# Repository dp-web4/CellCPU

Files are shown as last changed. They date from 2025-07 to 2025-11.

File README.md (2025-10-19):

# CellCPU Documentation

**ModBatt Battery Management System - Individual Cell Controller**

## Overview

The CellCPU is a **production-ready** foundational component of ModBatt's hierarchical battery management system, providing individual cell monitoring and control for lithium-ion battery applications. Each CellCPU manages a single cell with precision voltage monitoring, temperature sensing, and active balancing control.

**Implementation Status**: ✅ **Complete and functional** - All core modules implemented with sophisticated interrupt-driven architecture.

### Quick Facts

- **Target Platform**: ATtiny45 microcontroller (8-bit AVR)
- **Cell Interface**: Direct monitoring of single lithium-ion cell
- **Temperature Sensor**: MCP9843 precision digital sensor
- **Communication**: Virtual UART at 20kbps in daisy-chain topology
- **Power Consumption**: <1mA typical operation
- **Scalability**: Up to 128 CellCPUs per ModuleCPU

## Web4 Ecosystem Context

CellCPU is the foundational layer of a **trust-native battery management system** demonstrating [Web4](https://github.com/dp-web4/web4) principles in production embedded hardware:

**Philosophy**: [Synchronism](https://github.com/dp-web4/Synchronism) - Distributed intelligence and scale-based autonomy
**Standard**: [Web4](https://github.com/dp-web4/web4) - Trust-native internet architecture with LCTs and MRH
**Implementation**: **CellCPU** (this) → [ModuleCPU](https://github.com/dp-web4/ModuleCPU) → [Pack-Controller](https://github.com/dp-web4/Pack-Controller-EEPROM)

### Web4 Integration

Each CellCPU operates as an autonomous agent with:
- **LCT Identity**: Unforgeable blockchain binding via hardware serial number
- **Markov Blanket**: VUART interface hides internal complexity from ModuleCPU
- **Local Intelligence**: Autonomous decision-making (balancing, error detection)
- **Trust Tensors**: ModuleCPU tracks T3 (Talent/Training/Temperament) and V3 (Veracity/Validity/Value)
- **Witnessed Presence**: ModuleCPU witnesses cell existence via VUART communication

See [WEB4_INTEGRATION.md](WEB4_INTEGRATION.md) for complete Web4 architecture details.

### Synchronism Principles

CellCPU demonstrates cosmic-to-silicon philosophy:
- **Scale-Based Autonomy**: Cell makes local decisions within module context
- **Markov Blankets**: VUART interface defines cell's reality boundary
- **Distributed Intelligence**: No central cell controller - intelligence emerges from hierarchy
- **Sensor Fusion**: Temperature + voltage + time → emergent "cell health"
- **Intent Dynamics**: Battery charge/discharge as metabolic intent propagation

See [SYNCHRONISM_PRINCIPLES.md](SYNCHRONISM_PRINCIPLES.md) for philosophical depth.

### Ecosystem Links

- [Synchronism Whitepaper](https://github.com/dp-web4/Synchronism/blob/main/whitepaper.md) - Universal principles
- [Web4 Standard](https://github.com/dp-web4/web4/blob/main/web4-standard/README.md) - Internet standard
- [ModBatt Web4 Examples](https://github.com/dp-web4/web4/blob/main/docs/modbatt_implementation_examples.md) - Code walkthroughs

**This is not just a battery controller - it's proof that Web4 trust architecture works in 4KB of flash memory.**

---

## Documentation Structure

### 📖 Core Documentation

#### [System Overview](docs/overview/README.md)
Complete system overview, architecture, and integration context within the ModBatt ecosystem.

- System role and responsibilities
- Hardware platform specifications  
- Communication protocol overview
- Performance characteristics
- Integration with ModuleCPU and Pack Controller

#### [Software Architecture](docs/overview/architecture.md)
Detailed firmware architecture and design patterns.

- Event-driven state machine design
- Module organization and dependencies
- Memory management strategies
- Interrupt architecture
- Error handling and safety systems

### 🔧 Hardware Documentation

#### [Hardware Platform](docs/hardware/README.md)
Comprehensive hardware platform documentation covering the ATtiny45 microcontroller and supporting components.

- ATtiny45 specifications and capabilities
- Pin configuration and multiplexing
- External component integration
- Power system design
- PCB layout considerations
- Environmental specifications

### 💻 Firmware Documentation

#### [Firmware Architecture](docs/firmware/README.md)
Complete firmware module documentation and implementation details.

- Module hierarchy and interfaces
- ADC voltage measurement system
- Virtual UART communication implementation
- Temperature sensor integration
- Platform abstraction layer
- Build system and optimization

#### [Cell Interface & Monitoring](docs/cell-interface/README.md)
Detailed cell monitoring and control system documentation.

- Voltage monitoring with 10-bit ADC
- Temperature sensing via I2C
- Active balancing control
- Safety and protection features
- Calibration and accuracy optimization
- Diagnostic capabilities

### 🔗 Communication System

#### [Communication with ModuleCPU](docs/communication/README.md)
Complete communication protocol and implementation documentation.

- Physical layer implementation
- Message format and structure
- Daisy-chain topology management
- Virtual UART timing and control
- Error handling and recovery
- Performance optimization

#### [Temperature Sensing](docs/temperature/README.md)
Comprehensive temperature monitoring system documentation.

- MCP9843 sensor integration
- I2C communication interface
- Thermal management and control
- Pin multiplexing with ADC
- Calibration and accuracy
- Error handling and diagnostics

### 🛠️ Development

#### [Development Environment](docs/development/README.md)
Complete development environment setup and workflow documentation.

- Required software tools (Microchip Studio, XC8)
- Hardware setup and programming
- Build process and optimization
- Testing and validation procedures
- Version control workflow
- Best practices and standards

#### [Implementation Status](docs/implementation-status.md)
**NEW**: Comprehensive review of actual implementation completeness and quality.

- Complete module implementation status
- Code quality assessment
- Production readiness evaluation
- Hardware validation priorities
- Integration testing recommendations

## Quick Start Guide

### 1. Development Environment Setup

```bash
# Required Tools
1. Download and install Microchip Studio 7.0+
2. Install XC8 Compiler v2.36+
3. Setup Atmel-ICE programmer/debugger
4. Clone the CellCPU repository

# Open Project
1. Launch Microchip Studio
2. File → Open → Project/Solution
3. Select CellCPU.cproj
4. Build → Build Solution (F7)
```

### 2. Hardware Configuration

```c
// Key hardware connections
Pin Configuration:
├── PB0: cell_up_tx    (Output to upstream cell)
├── PB1: cell_dn_rx    (Input from downstream)
├── PB2: I2C SDA       (Temperature sensor)
├── PB3: I2C SCL/ADC3  (Temperature + voltage)
├── PB4: cell_up_rx    (Input from upstream)
└── PB5: cell_dn_tx    (Output to downstream)

Power: 3.0V to 5.5V (5.0V nominal)
Programming: 6-pin ISP header
```

### 3. Basic Usage

```c
// Actual implemented functionality
System Operation:
1. Interrupt-driven Virtual UART communication (20kbps)
2. Pin-multiplexed voltage (ADC) and temperature (I2C) sensing
3. MCP9843 EVENT pin control for discharge balancing
4. Sophisticated timer-based bit timing with guard bits
5. Automatic chain position detection and data relay
6. Robust I2C bit-banged implementation with ACK handling
7. Power-efficient ADC enable/disable cycling

// Core modules all implemented:
├── adc.c - Complete ADC implementation with power management
├── I2c.c - Full bit-banged I2C with timing quantization  
├── mcp9843.c - Complete temperature sensor driver
├── vUART.c - Sophisticated interrupt-driven communication
└── main.c - Complete state machine coordination
```

## Key Features

### 🔋 Cell Monitoring
- **Voltage**: 10-bit ADC with 1.1V reference, ~4.3mV resolution
- **Temperature**: MCP9843 sensor, ±0.5°C accuracy, 0.0625°C resolution
- **Range**: 2.0V-5.0V cell voltage, -40°C to +125°C temperature

### 📡 Communication
- **Protocol**: Custom serial over Virtual UART
- **Speed**: 20kbps (50μs bit time)
- **Topology**: Daisy-chain up to 128 cells
- **Latency**: <5ms per cell response time

### ⚡ Control & Safety
- **Balancing**: Active discharge via MCP9843 EVENT pin
- **Protection**: Voltage and temperature limit monitoring
- **Safety**: Fail-safe operation on communication loss
- **Power**: <1mA typical, <100μA idle

### 🎯 Performance
- **Memory**: 4KB Flash (62% used), 256B SRAM (58% used)
- **Real-time**: Interrupt-driven with timer-based precision timing
- **Communication**: Sophisticated Virtual UART with guard bits and relay
- **I2C Implementation**: Professional bit-banged with timing quantization
- **Power Management**: ADC power cycling, efficient pin multiplexing
- **Reliability**: Comprehensive error handling and recovery mechanisms

## System Integration

### ModBatt Architecture Context

```
Vehicle Control Unit (VCU)
    ↓ CAN Bus
Pack Controller (STM32WB55)
    ↓ CAN Bus
ModuleCPU (ATmega64M1) ←→ Up to 128 × CellCPU (ATtiny45)
    ↓                              ↓
Battery Module                Li-ion Cells
```

### Communication Flow

```
Command Flow (Downstream):
ModuleCPU → CellCPU(Last) → CellCPU(Middle) → CellCPU(First)

Data Flow (Upstream):  
ModuleCPU ← CellCPU(Last) ← CellCPU(Middle) ← CellCPU(First)
```

## Contributing

### Development Workflow

1. **Feature Development**: Create feature branch from `develop`
2. **Code Review**: Submit pull request with comprehensive testing
3. **Integration**: Merge to `develop` after approval
4. **Release**: Create release branch for final testing
5. **Production**: Merge to `main` and tag release

### Coding Standards

- **Style**: K&R brace style, 4-space indentation
- **Documentation**: Comprehensive function headers and inline comments
- **Testing**: Unit tests and integration validation required
- **Performance**: Memory and timing optimization mandatory

## License and Patents

### Software License

This software is licensed under the **GNU Affero General Public License v3.0 or later** (AGPL-3.0-or-later).

See [LICENSE](LICENSE) for full license text.
See [LICENSE_SUMMARY.md](LICENSE_SUMMARY.md) for a summary of software vs. hardware licensing.

### Patents

Protected by US Patents:
- **11,380,942**: Distributed battery management with autonomous cell controllers
- **11,469,470**: Hierarchical battery management architecture
- **11,575,270**: Related pack control systems

**Patent Grant**: A limited patent grant for the software is provided under the AGPL-3.0 license scope. See [PATENTS.md](PATENTS.md) for details.

**Hardware Licensing**: Separate from software. See `docs/legal/ModBatt_Product_License.pdf` for hardware manufacturing licensing.

### Copyright

© 2023-2025 Modular Battery Technologies, Inc.

**Open Source Release**: October 2025 - Part of the Web4 trust-native ecosystem demonstration.

## Support and Contact

For technical support, development questions, or collaboration opportunities:

- **Technical Documentation**: See individual module documentation
- **Development Issues**: Check troubleshooting sections in relevant docs
- **Hardware Support**: Refer to hardware platform documentation
- **Communication Protocol**: See communication system documentation

---

## Related Projects

This repository can be viewed as demonstrating patterns of distributed trust and verifiable provenance in embedded systems.

**Related**: [Web4](https://github.com/dp-web4/web4) (trust architecture) • [Synchronism](https://github.com/dp-web4/Synchronism) (conceptual framing)

---

**Note**: This documentation covers the CellCPU firmware component of the ModBatt battery management system. For complete system documentation, refer to the Pack Controller and ModuleCPU documentation.

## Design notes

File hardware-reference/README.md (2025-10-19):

# CellCPU Hardware Reference Designs

**Status**: Reference designs for educational and non-commercial use
**Patent Coverage**: Protected by US Patent 11,380,942 (Distributed battery management with autonomous cell controllers)
**Last Updated**: October 2025

---

## Overview

This directory contains reference hardware designs for implementing the CellCPU concept - an autonomous cell-level battery management controller based on ATtiny45. These designs demonstrate one possible hardware implementation of the patented distributed battery management architecture.

**Contents**:
- KiCad schematics and PCB layouts
- Bill of Materials (BOM)
- Manufacturing files

---

## Patent Coverage

These hardware designs implement concepts covered by multiple patents in the ModBatt patent portfolio:

### Complete Patent List

**Modular Battery Technologies, Inc. Patent Portfolio**:

1. **US 11,380,942** (PCT/US21/50518) - *High Voltage Battery Module with Series Connected Cells and Internal Relays*
   - Filed: November 2, 2020 | Issued: July 5, 2022
   - Module with series connected cells and relays

2. **US 11,469,470** (PCT/US21/53798) - *Battery Module with Series Connected Cells, Internal Relays and Internal Battery Management System*
   - Filed: January 4, 2021 | Issued: October 11, 2022
   - Cell monitoring/conditioning circuit, PCBAs, methods

3. **US 11,563,241** - *Apparatus and Methods for Removable Battery Module with Internal Relay and Internal Controller*
   - Filed: February 10, 2021 | Issued: December 14, 2022
   - Authentication methods and circuits

4. **US 11,575,270** (PCT/US21/55047) - *Battery Module with Series Connected Cells, Internal Relays and Internal Battery Management System*
   - Filed: February 22, 2021 (CIP) | Issued: February 7, 2023
   - AC coupled comms and methods

5. **US 11,699,817** (PCT/US21/54434) - *Apparatus and Methods for Removable Battery Module with Internal Relay and Internal Controller*
   - Filed: March 31, 2021 | Issued: July 11, 2023
   - System, pack and module controllers, blockchain

6. **US 11,477,027** (PCT/US21/55813) - *Apparatus and Methods for Management of Controlled Objects*
   - Filed: May 11, 2021 | Issued: October 18, 2022
   - Multi-domain management of controlled objects, LCT/blockchain

7. **US 11,936,008** (PCT/US21/60860) - *Electrical Power System with Removable Battery Modules*
   - Filed: November 17, 2021 | Issued: March 19, 2024
   - Dissimilar modules in parallel

8. **US 12,278,913** (PCT/US22/24797) - *Apparatus and Methods for Management of Controlled Objects*
   - Filed: March 31, 2022 | Issued: April 15, 2025
   - Linking of identifiable records

9. **US 11,876,250** (PCT/US22/xxx) - *High Voltage Battery Module with Series Connected Cells and Internal Relays*
   - Filed: May 31, 2022 | Issued: January 16, 2024
   - Dissimilar relays, PLC control bus, linear and PWM modes

10. **US 12,046,722** - *Electrical Power System with Removable Battery Modules*
    - Filed: December 12, 2022 | Issued: July 23, 2024
    - Vehicle and stationary installations having a power system, energizing a bus

11. **US 12,405,309** - *Low Cost Battery Cell Monitoring Circuit*
    - Filed: January 3, 2023 | Issued: September 2, 2025
    - Low cost ASIC

12. **US 12,136,739** - *Low Cost Battery Cell Monitoring Circuit*
    - Filed: December 14, 2023 | Issued: November 5, 2024
    - Low cost ASIC methods

13. **US 12,142,737** - *Electrical Power System with Removable Battery Modules*
    - Filed: December 14, 2023 | Issued: November 12, 2024

14. **US 18/935,265** - *High Voltage Battery Module with 1-Phase and 3-Phase AC Output*
    - Filed: November 1, 2024 | Status: Pending

**Assignee**: Modular Battery Technologies, Inc.
**Inventors**: Dennis Palatov, et al.

### Key Patented Concepts in CellCPU Hardware

- Cell-level autonomous controllers with local intelligence
- Virtual UART communication in daisy-chain topology
- Distributed temperature and voltage monitoring
- Markov blanket interface hiding internal cell complexity
- Low-cost cell monitoring circuits and ASICs
- Authentication methods for cell controllers

---

## License and Usage Terms

### Software License
The **CellCPU firmware** (parent directory) is licensed under **AGPL-3.0-or-later** with a patent grant for software use. See `../LICENSE` for details.

### Hardware Reference Designs
These hardware reference designs are provided under the following terms:

#### ✅ Permitted Uses (Non-Commercial Patent Grant)

You MAY use these designs **without a commercial hardware license** for:

1. **Educational Use**: Academic research, teaching, and learning
2. **Personal/Hobby Use**: Individual projects and experimentation
3. **Research & Development**: Prototyping and testing new concepts
4. **Open Source Development**: Contributing to AGPL-licensed software improvements

**Conditions**:
- No commercial sale or distribution of manufactured hardware
- Acknowledge patent and provide attribution
- Derivative works must include similar non-commercial use notice
- Software modifications must comply with AGPL-3.0-or-later

#### ❌ Restricted Uses (Requires Commercial License)

You MUST obtain a commercial hardware license from Modular Battery Technologies, Inc. for:

1. **Commercial Manufacturing**: Producing hardware for sale
2. **Commercial Products**: Incorporating designs into commercial battery products
3. **Revenue Generation**: Any use where hardware generates revenue directly or indirectly
4. **OEM Integration**: Selling products that include these designs

**Contact**: For commercial licensing inquiries, contact Modular Battery Technologies, Inc.

---

## Technical Scope

These reference designs demonstrate:

- **Cell Controller**: ATtiny45-based autonomous controller per cell
- **Temperature Sensing**: MCP9843 I²C temperature sensor integration
- **Virtual UART**: Software-based serial communication at 20kbps
- **Daisy-Chain Topology**: Up to 128 cells in series connection
- **Voltage Monitoring**: Per-cell voltage measurement architecture
- **Relay Control**: Cell bypass/isolation relay interface

**Voltage Range**: Designed for 13-cell strings (48V nominal LiFePO4)

---

## AS-IS Disclaimer and Limitations

### ⚠️ NO WARRANTY

**THESE HARDWARE REFERENCE DESIGNS ARE PROVIDED "AS IS" WITHOUT WARRANTY OF ANY KIND, EXPRESS OR IMPLIED, INCLUDING BUT NOT LIMITED TO THE WARRANTIES OF MERCHANTABILITY, FITNESS FOR A PARTICULAR PURPOSE, TITLE, AND NON-INFRINGEMENT.**

### Specific Disclaimers

1. **No Guarantee of Functionality**: These designs may contain errors, omissions, or may not function as intended
2. **No Safety Certification**: Designs have NOT been certified for safety (UL, CE, etc.)
3. **High Voltage Hazard**: Battery systems operate at dangerous voltages - **risk of electric shock, fire, explosion**
4. **Chemical Hazard**: Lithium battery failures can cause fire, toxic fumes, and explosions
5. **No Professional Engineering Review**: Use at your own risk - consult qualified professionals
6. **Rapidly Evolving**: These designs may be outdated or superseded

### 🚨 Battery Safety Warning

**DANGER**: Lithium-ion and LiFePO4 batteries are potentially hazardous.

- **Thermal runaway** can cause fires and explosions
- **Improper charging** can cause battery damage and fire
- **Short circuits** can cause severe burns and fire
- **Cell imbalance** can reduce lifespan and create safety hazards

**You are solely responsible for:**
- Proper safety engineering and testing
- Compliance with electrical codes and regulations
- Fire suppression and containment systems
- Proper charging and monitoring equipment
- Insurance and liability coverage

---

## Limitation of Liability

**IN NO EVENT SHALL MODULAR BATTERY TECHNOLOGIES, INC., ITS AFFILIATES, OR CONTRIBUTORS BE LIABLE FOR ANY DIRECT, INDIRECT, INCIDENTAL, SPECIAL, EXEMPLARY, OR CONSEQUENTIAL DAMAGES (INCLUDING, BUT NOT LIMITED TO, PROCUREMENT OF SUBSTITUTE GOODS OR SERVICES; LOSS OF USE, DATA, OR PROFITS; BUSINESS INTERRUPTION; PROPERTY DAMAGE; PERSONAL INJURY; OR DEATH) HOWEVER CAUSED AND ON ANY THEORY OF LIABILITY, WHETHER IN CONTRACT, STRICT LIABILITY, OR TORT (INCLUDING NEGLIGENCE OR OTHERWISE) ARISING IN ANY WAY OUT OF THE USE OF THESE DESIGNS, EVEN IF ADVISED OF THE POSSIBILITY OF SUCH DAMAGE.**

---

## Regulatory Compliance

### Your Responsibility

If you manufacture hardware based on these designs, YOU are responsible for:

1. **Electrical Safety**: UL/CSA/CE compliance as required
2. **FCC/EMC Compliance**: Radio frequency emissions and immunity
3. **Environmental**: RoHS, REACH, WEEE directives
4. **Transportation**: UN38.3 battery shipping requirements (if applicable)
5. **Local Codes**: Electrical codes and building codes in your jurisdiction

### No Compliance Warranty

**These designs have NOT been tested for regulatory compliance.** You must perform your own testing and certification.

---

## Design Files Information

### KiCad Version
Designs created with KiCad EDA (exact version in `.kicad_pro` files)

### File Structure
- `.kicad_sch` - Schematic files (hierarchical sheets)
- `.kicad_pcb` - PCB layout files
- `.csv` / `.ods` - Bill of Materials
- `mfg/` - Manufacturing output files (Gerbers, drill files, pick-and-place)

### Viewing and Editing
1. Download and install KiCad: https://www.kicad.org/
2. Open `.kicad_pro` project file
3. Libraries may need to be remapped on first open

---

## Attribution and Derivative Works

If you create derivative works based on these designs:

1. **Acknowledge the Source**:
   ```
   Based on CellCPU hardware reference designs
   Copyright (c) 2024-2025 Modular Battery Technologies, Inc.
   https://github.com/dp-web4/CellCPU
   ```

2. **Maintain Patent Notice**: Include reference to ModBatt patent portfolio (see Patent Coverage section)

3. **Propagate Non-Commercial Terms**: If distributing derivatives, include similar non-commercial use restrictions

4. **No Endorsement**: Do not imply that your derivative work is endorsed by Modular Battery Technologies, Inc.

---

## Support and Contributions

### No Support Commitment
These reference designs are provided without support. No assistance is guaranteed.

### Community Contributions
Improvements to these reference designs are welcome via pull requests:
- Clearly document changes and reasoning
- Maintain safety-critical design margins
- Include SPDX license headers if adding new files
- Sign-off on contributions (Developer Certificate of Origin)

---

## Relationship to Software License

**Key Distinction**:
- **Software (CellCPU firmware)**: AGPL-3.0-or-later with broad patent grant for software use
- **Hardware (these designs)**: Non-commercial patent grant only; commercial use requires separate license

**Why the Difference?**
- Software improvements benefit the ecosystem when shared (AGPL ensures sharing)
- Hardware manufacturing involves significant capital investment and safety liability
- Patent coverage primarily relates to hardware architecture and topology

**Can I modify the software for use on different hardware?**
- Yes! The AGPL-3.0 software license and patent grant apply to the software
- You can run modified CellCPU software on your own hardware implementations
- Commercial hardware sales still require a hardware patent license

---

## Questions?

**Technical Questions**: Open an issue on GitHub (https://github.com/dp-web4/CellCPU/issues)
**Commercial Licensing**: Contact Modular Battery Technologies, Inc.
**Safety Concerns**: Consult a qualified electrical engineer and safety professional

---

## Legal Summary

| **Aspect** | **Terms** |
|---|---|
| **Software License** | AGPL-3.0-or-later (see `../LICENSE`) |
| **Hardware Designs** | Reference only - non-commercial patent grant |
| **Patents** | 14 US patents (1 pending) - commercial use requires license |
| **Warranty** | NONE - "AS IS" |
| **Liability** | User assumes all risk and liability |
| **Safety** | NOT certified - dangerous high voltage battery application |
| **Commercial Use** | Requires separate commercial license agreement |

---

**© 2024-2025 Modular Battery Technologies, Inc.**
**Patents**: 14 US patents covering battery management systems (see Patent Coverage section)
**Reference designs provided for educational and non-commercial use only**

---

*Last updated: October 2025*
*For latest terms, see https://github.com/dp-web4/CellCPU*

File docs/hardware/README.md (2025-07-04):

# CellCPU Hardware Platform

## Table of Contents

1. [Overview](#overview)
2. [ATtiny45 Microcontroller](#attiny45-microcontroller)
3. [Pin Configuration](#pin-configuration)
4. [External Components](#external-components)
5. [Power System](#power-system)
6. [PCB Design Considerations](#pcb-design-considerations)
7. [Environmental Specifications](#environmental-specifications)
8. [Manufacturing and Assembly](#manufacturing-and-assembly)

## Overview

The CellCPU hardware platform is built around the ATtiny45 microcontroller, chosen for its optimal balance of functionality, cost, and size for individual cell monitoring applications. The design emphasizes minimal component count, high reliability, and integration into battery module assemblies.

### Hardware Design Goals

- **Minimal Footprint**: Smallest possible PCB size for integration into cell assemblies
- **Cost Optimization**: Lowest BOM cost while maintaining required functionality
- **High Reliability**: Automotive-grade components and robust design practices
- **EMI/EMC Compliance**: Proper filtering and layout for electromagnetic compatibility
- **Thermal Management**: Operation across automotive temperature ranges

### Block Diagram

```
┌─────────────────────────────────────────────────────────────────┐
│                    CellCPU Hardware Block Diagram               │
├─────────────────────────────────────────────────────────────────┤
│ Power Input (3.0V - 5.5V)                                      │
│ ├── Reverse Protection                                         │
│ ├── Filtering (C1, C2)                                        │
│ └── Voltage Regulation (if needed)                            │
├─────────────────────────────────────────────────────────────────┤
│ ATtiny45 Microcontroller                                        │
│ ├── Pin 1: PB5 (cell_dn_tx)                                   │
│ ├── Pin 2: PB3 (I2C SCL / ADC3)                              │
│ ├── Pin 3: PB4 (cell_up_rx)                                   │
│ ├── Pin 4: GND                                                │
│ ├── Pin 5: PB0 (cell_up_tx)                                   │
│ ├── Pin 6: PB1 (cell_dn_rx)                                   │
│ ├── Pin 7: PB2 (I2C SDA)                                      │
│ └── Pin 8: VCC                                                │
├─────────────────────────────────────────────────────────────────┤
│ Temperature Sensor (MCP9843)                                   │
│ ├── I2C Interface (SDA, SCL)                                  │
│ ├── EVENT Pin (discharge control)                             │
│ └── Power Supply (3.3V)                                       │
├─────────────────────────────────────────────────────────────────┤
│ Voltage Measurement                                             │
│ ├── Resistor Divider Network                                  │
│ ├── Input Protection (TVS)                                    │
│ └── RC Filter                                                 │
├─────────────────────────────────────────────────────────────────┤
│ Communication Interface                                         │
│ ├── Virtual UART (4 pins)                                     │
│ ├── Signal Conditioning                                       │
│ └── ESD Protection                                            │
├─────────────────────────────────────────────────────────────────┤
│ Discharge Control                                              │
│ ├── FET Driver (external)                                     │
│ ├── Load Resistor (external)                                  │
│ └── Thermal Management                                         │
└─────────────────────────────────────────────────────────────────┘
```

## ATtiny45 Microcontroller

### Core Specifications

```
ATtiny45 Detailed Specifications:
├── Architecture: 8-bit AVR RISC
├── Core: AVR enhanced RISC architecture
├── Performance: 8 MIPS at 8MHz
├── Operating Voltage: 2.7V to 5.5V
├── Operating Frequency: 0 to 20MHz (external clock)
├── Internal Clock: 8MHz RC oscillator (±10% accuracy)
├── Power Consumption:
│   ├── Active: 1.5mA at 1MHz, 3V
│   ├── Idle: 0.5mA at 1MHz, 3V
│   └── Power-down: 0.1μA at 3V
└── Temperature Range: -40°C to +85°C (industrial)
```

### Memory Architecture

```
Memory Organization:
├── Flash Program Memory: 4KB (4,096 bytes)
│   ├── Application Section: 0x0000 - 0x0FFF
│   ├── Boot Loader Section: Not used
│   └── Application Flash End: 0x0FFF
├── SRAM Data Memory: 256 bytes
│   ├── 32 General Purpose Registers: 0x00 - 0x1F
│   ├── 64 I/O Registers: 0x20 - 0x5F
│   └── Internal SRAM: 0x60 - 0x15F (256 bytes)
├── EEPROM Data Memory: 256 bytes
│   ├── Address Range: 0x000 - 0x0FF
│   ├── Endurance: 100,000 write/erase cycles
│   └── Retention: 20 years at 85°C
└── Fuse Bits: Low, High, Extended
    ├── Clock Selection
    ├── Brown-out Detection
    └── Debug Interface
```

### Peripheral Systems

#### ADC (Analog-to-Digital Converter)
```
ADC Specifications:
├── Resolution: 10-bit (0-1023 counts)
├── Channels: 4 single-ended (ADC0-ADC3)
├── Reference Voltage:
│   ├── VCC: Power supply voltage
│   ├── External AREF: External reference
│   ├── Internal 1.1V: ±10% accuracy
│   └── Internal 2.56V: ±10% accuracy (not used)
├── Conversion Time: 13 - 260μs (13 ADC clock cycles)
├── Sample Rate: Up to 15kSPS at maximum resolution
├── Input Impedance: 100MΩ
├── DNL: ±0.5 LSB
└── INL: ±1 LSB
```

#### Timer/Counter0
```
Timer0 Features:
├── Type: 8-bit Timer/Counter
├── Clock Sources:
│   ├── Internal clock (no prescaling)
│   ├── Internal clock with prescaler (8, 64, 256, 1024)
│   └── External clock on T0 pin
├── Operating Modes:
│   ├── Normal Mode (overflow)
│   ├── CTC (Clear Timer on Compare)
│   ├── Fast PWM
│   └── Phase Correct PWM
├── Compare Channels: 2 (A and B)
├── Interrupts: Overflow, Compare Match A, Compare Match B
└── Used For: Virtual UART bit timing
```

#### Universal Serial Interface (USI)
```
USI Capabilities:
├── Three-wire SPI Master/Slave
├── Two-wire I2C-compatible Master/Slave  
├── UART (software implementation required)
├── Data Register: 8-bit shift register
├── Control: Start condition detector
├── Clock: External or Timer0 Compare Match
└── Interrupts: Start condition, Counter overflow
```

### Pin Configuration Details

```
ATtiny45 Pin Mapping:
                    ┌─────────┐
         PB5/RESET ─│1      8│─ VCC
    PB3/ADC3/SCL   ─│2      7│─ PB2/SDA/ADC1
         PB4/ADC2  ─│3      6│─ PB1/ADC0
              GND  ─│4      5│─ PB0/OC0A
                    └─────────┘

Pin Functions (CellCPU Usage):
├── Pin 1 (PB5): cell_dn_tx output
├── Pin 2 (PB3): I2C SCL + ADC3 (cell voltage)
├── Pin 3 (PB4): cell_up_rx input  
├── Pin 4 (GND): Ground reference
├── Pin 5 (PB0): cell_up_tx output
├── Pin 6 (PB1): cell_dn_rx input
├── Pin 7 (PB2): I2C SDA
└── Pin 8 (VCC): Power supply
```

### Electrical Characteristics

```
DC Characteristics (TA = -40°C to +85°C, VCC = 2.7V to 5.5V):
├── Supply Current:
│   ├── Active Mode: 0.2mA/MHz (typical)
│   ├── Idle Mode: 0.03mA/MHz (typical)
│   ├── Power-down Mode: 0.1μA (typical)
│   └── ADC Active: +320μA (typical)
├── I/O Pin Characteristics:
│   ├── Input Low Voltage (VIL): -0.5V to 0.3×VCC
│   ├── Input High Voltage (VIH): 0.6×VCC to VCC+0.5V
│   ├── Output Low Voltage (VOL): 0.7V max (IOL = 20mA)
│   ├── Output High Voltage (VOH): VCC-0.7V min (IOH = 20mA)
│   ├── Input Leakage Current: ±1μA max
│   └── Pull-up Resistor: 20kΩ to 50kΩ
├── ADC Characteristics:
│   ├── Absolute Accuracy: ±2 LSB (10-bit)
│   ├── Integral Non-linearity: ±0.5 LSB
│   ├── Differential Non-linearity: ±0.5 LSB
│   ├── Input Voltage: 0V to VCC
│   └── Conversion Time: 65-260μs
└── Clock Characteristics:
    ├── Internal RC: 8.0MHz ±10% (3V, 25°C)
    ├── External Clock: 0-20MHz
    └── Crystal Oscillator: Not available on ATtiny45
```

## Pin Configuration

### Detailed Pin Functions

#### Pin 1 (PB5/RESET): cell_dn_tx
```
cell_dn_tx Configuration:
├── Direction: Output
├── Function: Transmit data to downstream cell or ModuleCPU
├── Logic Levels:
│   ├── Logic 0 (Assert): 0V to 0.7V
│   └── Logic 1 (Deassert): VCC-0.7V to VCC
├── Drive Capability: 20mA maximum
├── Default State: High (deasserted)
├── Signal Inversion: Active low for UART start bit
└── Protection: Series resistor + ESD diode
```

#### Pin 2 (PB3/ADC3): I2C SCL + Cell Voltage ADC
```
Dual Function Pin Configuration:
├── Primary: I2C Serial Clock (SCL)
│   ├── Direction: Open-drain with pull-up
│   ├── Pull-up: 4.7kΩ external resistor
│   ├── Clock Rate: 100kHz (standard I2C)
│   └── Logic Levels: I2C compliant
├── Secondary: ADC3 Cell Voltage Input
│   ├── Input Range: 0V to 1.1V (with internal reference)
│   ├── Input Impedance: >100MΩ
│   ├── Protection: TVS diode + RC filter
│   └── Conversion: 10-bit resolution
├── Switching: Software controlled
│   ├── I2C Mode: GPIO + USI
│   └── ADC Mode: ADC peripheral
└── Timing: I2C operations completed before ADC measurement
```

#### Pin 3 (PB4): cell_up_rx
```
cell_up_rx Configuration:
├── Direction: Input
├── Function: Receive data from upstream cell
├── Input Characteristics:
│   ├── Logic 0: 0V to 0.3×VCC
│   ├── Logic 1: 0.6×VCC to VCC
│   ├── Input Impedance: >100MΩ
│   └── Input Capacitance: ~10pF
├── Pull-up: Internal 20kΩ to 50kΩ
├── Interrupt: Pin change interrupt (PCINT4)
├── Protection: ESD diode to VCC and GND
└── Signal Conditioning: RC filter for noise immunity
```

#### Pin 5 (PB0): cell_up_tx
```
cell_up_tx Configuration:
├── Direction: Output
├── Function: Transmit data to upstream cell
├── Drive Capability: 20mA maximum
├── Logic Levels: CMOS compatible
├── Default State: High (deasserted)
├── PWM Capability: OC0A output (not used)
└── Protection: Series resistor + ESD diode
```

#### Pin 6 (PB1): cell_dn_rx
```
cell_dn_rx Configuration:
├── Direction: Input
├── Function: Receive commands from downstream cell or ModuleCPU
├── Interrupt: Pin change interrupt (PCINT1)
├── Pull-up: Internal resistor enabled
├── Signal Processing: Edge detection for UART start bit
├── Noise Filtering: Software debouncing
└── Protection: ESD diode protection
```

#### Pin 7 (PB2): I2C SDA
```
I2C SDA Configuration:
├── Direction: Bidirectional (open-drain)
├── Function: I2C Serial Data Line
├── Pull-up: 4.7kΩ external resistor to VCC
├── Logic Levels: I2C specification compliant
├── Drive Capability: Open-drain only
├── Input Hysteresis: Schmitt trigger input
└── Protection: ESD protection to VCC and GND
```

### Pin Multiplexing Strategy

```c
// Pin multiplexing implementation
void configurePinForI2C(void) {
    // Configure PB3 as I2C SCL
    SCL_SET_OUTPUT();
    SCL_HIGH();
    
    // Configure PB2 as I2C SDA  
    SDA_SET_OUTPUT();
    SDA_HIGH();
}

void configurePinForADC(void) {
    // Configure PB3 as ADC input
    SCL_SET_INPUT();
    SCL_LOW();  // Disable pull-up
    
    // Set ADC multiplexer to ADC3 (PB3)
    ADMUX = (1 << MUX1) | (1 << MUX0) | (1 << REFS1);
}

// Usage pattern
void performMeasurements(void) {
    // 1. Read voltage using ADC
    configurePinForADC();
    uint16_t voltage = ADCRead();
    
    // 2. Read temperature using I2C
    configurePinForI2C();
    uint16_t temperature = MCP9843ReadTemperature();
    
    // 3. Return to ADC mode for next cycle
    configurePinForADC();
}
```

## External Components

### MCP9843 Temperature Sensor

```
MCP9843 Specifications:
├── Package: 8-pin DFN (2mm × 3mm × 0.9mm)
├── Supply Voltage: 2.7V to 5.5V
├── Supply Current: 200μA typical
├── Temperature Range: -40°C to +125°C
├── Accuracy: ±0.5°C (typical), ±1°C (max)
├── Resolution: 0.0625°C (12-bit)
├── Conversion Time: 250ms maximum
├── Interface: I2C (400kHz max)
├── I2C Address: 0x30 (A2=A1=A0=0)
├── Alert/Event Pin: Open-drain output
└── Features: User-programmable temperature limits
```

#### MCP9843 Integration
```c
// Temperature sensor interface
#define MCP9843_ADDR            0x30
#define MCP9843_REG_TEMP        0x05
#define MCP9843_REG_CONFIG      0x01

// Temperature reading with error handling
int16_t MCP9843ReadTemperature(void) {
    uint8_t tempData[2];
    
    // Start I2C transaction
    if (I2CStart()) {
        if (I2CWriteByte(MCP9843_ADDR << 1)) {  // Write address
            if (I2CWriteByte(MCP9843_REG_TEMP)) {  // Register address
                if (I2CRepeatedStart()) {
                    if (I2CWriteByte((MCP9843_ADDR << 1) | 1)) {  // Read address
                        tempData[0] = I2CReadByte(true);   // MSB with ACK
                        tempData[1] = I2CReadByte(false);  // LSB with NACK
                        I2CStop();
                        
                        // Convert to temperature
                        int16_t temp = (tempData[0] << 8) | tempData[1];
                        temp >>= 4;  // Remove unused bits
                        return temp; // In 0.0625°C units
                    }
                }
            }
        }
    }
    
    I2CStop();
    return TEMPERATURE_ERROR_VALUE;
}

// Event pin control for discharge FET
bool MCP9843SetEventPin(bool bHigh) {
    uint8_t config = 0x00;  // Default configuration
    
    if (bHigh) {
        config |= 0x01;  // Set event pin high
    }
    
    return I2CWriteRegister(MCP9843_ADDR, MCP9843_REG_CONFIG, config);
}
```

### Voltage Measurement Circuit

```
Voltage Divider Design:
├── Cell Voltage Range: 2.5V to 4.2V (typical Li-ion)
├── ADC Reference: 1.1V internal reference
├── ADC Input Range: 0V to 1.1V
├── Divider Ratio: ~4:1 (for 4.4V max input)
├── R1 (High Side): 30kΩ ±1%
├── R2 (Low Side): 10kΩ ±1%
├── Input Protection: 5.1V TVS diode
├── Anti-alias Filter: 100Ω + 1nF
└── Input Impedance: 40kΩ (low impact on cell)

Calculation:
Vout = Vin × (R2 / (R1 + R2))
Vout = Vin × (10k / (30k + 10k)) = Vin × 0.25

For 4.2V cell: Vout = 4.2V × 0.25 = 1.05V (within 1.1V reference)
ADC counts = (1.05V / 1.1V) × 1023 = 975 counts
Resolution = 1.1V / 1023 = 1.075mV per count
Cell resolution = 1.075mV / 0.25 = 4.3mV per count
```

#### ADC Interface Implementation
```c
// ADC configuration and reading
void ADCInit(void) {
    // Configure ADC
    ADMUX = (1 << REFS1) |          // Internal 1.1V reference
            (1 << MUX1) | (1 << MUX0); // ADC3 (PB3)
    
    ADCSRA = (1 << ADEN) |          // Enable ADC
             (1 << ADPS2) | (1 << ADPS1) | (1 << ADPS0); // Prescaler /128
}

uint16_t ADCRead(void) {
    // Start conversion
    ADCSRA |= (1 << ADSC);
    
    // Wait for conversion complete
    while (ADCSRA & (1 << ADSC));
    
    // Read result (10-bit)
    uint16_t result = ADCL;
    result |= (ADCH << 8);
    
    return result;
}

// Convert ADC reading to millivolts
uint16_t ADCToMillivolts(uint16_t adcValue) {
    // Using integer math for efficiency
    // 1100mV reference, 1023 max count, 4:1 divider
    uint32_t millivolts = (uint32_t)adcValue * 1100 * 4;
    millivolts /= 1023;
    return (uint16_t)millivolts;
}
```

### Communication Interface Components

```
Signal Conditioning:
├── ESD Protection: 
│   ├── TVS diodes on all communication pins
│   ├── Voltage rating: 6V (above VCC max)
│   └── Capacitance: <10pF
├── Series Resistors:
│   ├── Value: 100Ω on all outputs
│   ├── Purpose: Current limiting and ringing reduction
│   └── Power rating: 1/8W minimum
├── Pull-up Resistors:
│   ├── I2C SDA/SCL: 4.7kΩ to VCC
│   ├── Communication RX pins: Internal pull-ups used
│   └── Tolerance: ±5%
└── RC Filters:
    ├── Input pins: 1kΩ + 100pF
    ├── Cutoff frequency: ~1.6MHz
    └── Purpose: EMI filtering and noise immunity
```

## Power System

### Power Supply Requirements

```
Power Supply Specifications:
├── Input Voltage Range: 3.0V to 5.5V
├── Nominal Operating Voltage: 5.0V
├── Current Consumption:
│   ├── Active (CPU + peripherals): 1.5mA typical
│   ├── I2C Transaction: +200μA for 1ms
│   ├── ADC Conversion: +320μA for 100μs
│   ├── Idle Mode: 0.5mA typical
│   └── Sleep Mode: <100μA
├── Power-On Reset: Hardware POR at 2.3V
├── Brown-Out Detection: Configurable (2.7V, 4.3V)
└── Decoupling: 100nF ceramic + 10μF tantalum
```

### Power Distribution

```c
// Power management implementation
void powerInit(void) {
    // Configure brown-out detection (optional)
    // Set via fuse bits during programming
    
    // Disable unused peripherals to save power
    PRR = (1 << PRTIM1) |   // Disable Timer1
          (1 << PRUSI);     // Keep USI enabled for I2C
    
    // Configure sleep mode
    set_sleep_mode(SLEEP_MODE_IDLE);
}

void enterLowPowerMode(void) {
    // Disable ADC to save power
    ADCSRA &= ~(1 << ADEN);
    
    // Set I2C pins to inputs to avoid current draw
    SCL_SET_INPUT();
    SDA_SET_INPUT();
    
    // Enter sleep mode
    sleep_mode();
    
    // Re-enable peripherals on wake
    ADCSRA |= (1 << ADEN);
}

// Power consumption optimization
void optimizePowerConsumption(void) {
    // Disable unused digital input buffers
    DIDR0 = (1 << ADC3D) |  // Disable digital input on ADC3
            (1 << ADC2D) |  // Disable digital input on ADC2
            (1 << ADC1D) |  // Disable digital input on ADC1
            (1 << ADC0D);   // Disable digital input on ADC0
    
    // Configure unused pins as outputs driving low
    // (Not applicable - all pins are used)
}
```

### Decoupling and Filtering

```
Power Supply Filtering:
├── Input Decoupling:
│   ├── 10μF tantalum capacitor (bulk storage)
│   ├── 100nF ceramic capacitor (high frequency)
│   ├── Placement: Close to VCC pin
│   └── ESR: <100mΩ for tantalum, <1Ω for ceramic
├── Analog Supply Filtering:
│   ├── Ferrite bead in VCC path to ADC
│   ├── Additional 100nF for ADC reference
│   └── Separate analog ground plane (if possible)
├── Digital Noise Suppression:
│   ├── 10Ω resistor + 100nF for digital VCC
│   ├── Separate decoupling for each IC
│   └── Ground plane for low impedance return
└── Layout Considerations:
    ├── Minimize loop areas
    ├── Keep switching signals away from analog
    ├── Use ground plane for thermal management
    └── Via stitching for layer transitions
```

## PCB Design Considerations

### Physical Constraints

```
PCB Specifications:
├── Board Size: 15mm × 20mm maximum (typical)
├── Layer Count: 2-layer (cost optimized)
├── Thickness: 1.6mm (standard)
├── Copper Weight: 1oz (35μm)
├── Via Size: 0.2mm drill, 0.45mm pad
├── Minimum Trace: 0.1mm (4 mil)
├── Minimum Space: 0.1mm (4 mil)
└── Surface Finish: HASL or ENIG
```

### Component Placement

```
Component Layout Priority:
├── High Priority (critical placement):
│   ├── ATtiny45: Central location
│   ├── MCP9843: Close to thermal sensing point
│   ├── Decoupling caps: Adjacent to power pins
│   └── Crystal (if used): Close to XTL pins
├── Medium Priority:
│   ├── Voltage divider: Near ADC input
│   ├── I2C pull-ups: Near I2C pins
│   ├── Communication connectors: Board edge
│   └── Programming connector: Accessible location
├── Low Priority:
│   ├── Test points: Convenient locations
│   ├── Status LEDs: Visible location
│   └── Mounting holes: Mechanical requirements
└── Keep-Out Areas:
    ├── High-current paths
    ├── Crystal oscillator
    ├── Antenna areas (if wireless)
    └── Mechanical clearances
```

### Routing Guidelines

```c
// PCB routing best practices
Routing Priority:
├── Power and Ground: Widest traces, shortest paths
├── Clock Signals: Controlled impedance, minimal vias
├── Analog Signals: Separate from digital, guard traces
├── I2C Signals: Matched lengths, proper pull-ups
├── Communication: Differential pairs where applicable
└── General I/O: Standard routing rules

Trace Width Calculations:
├── Power (VCC): 0.5mm (20 mil) for 100mA
├── Ground: Pour/plane preferred
├── Signal traces: 0.2mm (8 mil) minimum
├── Clock traces: 0.15mm (6 mil) for 50Ω
├── I2C: 0.2mm (8 mil) with 4.7kΩ pull-up
└── ADC input: 0.1mm (4 mil) with guard
```

### Thermal Considerations

```
Thermal Management:
├── Heat Sources:
│   ├── ATtiny45: ~15mW at 5V, 3mA
│   ├── MCP9843: ~1mW at 5V, 200μA
│   ├── Discharge FET: External (high power)
│   └── Total on-board: <20mW
├── Heat Dissipation:
│   ├── Copper pour for thermal spreading
│   ├── Thermal vias to back side
│   ├── Component spacing for airflow
│   └── Thermal interface to cell assembly
├── Temperature Rise:
│   ├── Junction to ambient: <20°C
│   ├── PCB thermal resistance: ~50°C/W
│   ├── Expected rise: <1°C for 20mW
│   └── Operating margin: >60°C
└── Design Verification:
    ├── Thermal simulation recommended
    ├── Prototype thermal testing
    ├── Worst-case power analysis
    └── Environmental chamber testing
```

## Environmental Specifications

### Operating Conditions

```
Environmental Requirements:
├── Temperature Range:
│   ├── Operating: -40°C to +85°C
│   ├── Storage: -55°C to +125°C
│   ├── Thermal Cycling: -40°C to +85°C (1000 cycles)
│   └── Thermal Shock: MIL-STD-883 Method 1011
├── Humidity:
│   ├── Operating: 5% to 95% RH (non-condensing)
│   ├── Storage: 5% to 95% RH (non-condensing)
│   └── Condensation: No permanent damage
├── Vibration:
│   ├── Random: 10g RMS, 20Hz to 2kHz
│   ├── Sinusoidal: 5g, 10Hz to 55Hz
│   ├── Shock: 50g, 11ms half-sine
│   └── Standard: UN 38.3 for battery applications
├── Altitude:
│   ├── Operating: -300m to +3000m
│   ├── Storage: -300m to +12000m
│   └── Pressure: 86kPa to 106kPa
└── Chemical Resistance:
    ├── Electrolyte: Resistant to common Li-ion electrolytes
    ├── Cleaning: Compatible with IPA and water
    ├── Conformal Coating: Recommended for harsh environments
    └── Salt Spray: 48 hours (if required)
```

### EMC/EMI Compliance

```
Electromagnetic Compatibility:
├── Emission Standards:
│   ├── CISPR 25: Automotive EMI limits
│   ├── FCC Part 15: Unintentional radiators
│   ├── EN 55025: Vehicle EMC requirements
│   └── Frequency Range: 150kHz to 1GHz
├── Immunity Standards:
│   ├── IEC 61000-4-2: ESD immunity (±8kV contact)
│   ├── IEC 61000-4-3: Radiated immunity (10V/m)
│   ├── IEC 61000-4-4: Fast transient immunity
│   └── IEC 61000-4-5: Surge immunity
├── Design Measures:
│   ├── Ground plane for low impedance return
│   ├── Ferrite beads on power and signal lines
│   ├── RC filters on inputs for HF suppression
│   ├── TVS diodes for transient protection
│   └── Shielding enclosure (if required)
└── Testing Requirements:
    ├── Pre-compliance testing during design
    ├── Full EMC testing on final product
    ├── In-vehicle testing for automotive applications
    └── Certification for regulatory compliance
```

## Manufacturing and Assembly

### Component Selection

```
Component Specifications:
├── Automotive Grade (AEC-Q100):
│   ├── ATtiny45A-SHR (automotive grade)
│   ├── MCP9843A (automotive temperature range)
│   ├── Resistors: Automotive grade, ±1% tolerance
│   └── Capacitors: X7R/X5R dielectric, automotive rated
├── Package Types:
│   ├── ATtiny45: SOIC-8 (hand-solderable alternative)
│   ├── MCP9843: DFN-8 (2mm×3mm)
│   ├── Resistors: 0603 (0402 if space constrained)
│   └── Capacitors: 0603 (0402 if space constrained)
├── Supplier Requirements:
│   ├── Tier 1 automotive suppliers preferred
│   ├── Automotive quality certifications
│   ├── Long-term availability (10+ years)
│   └── Change notification processes
└── Cost Targets:
    ├── Total BOM: <$3.00 in volume
    ├── ATtiny45: ~$0.80
    ├── MCP9843: ~$0.90
    ├── Passives: ~$0.30
    └── PCB: ~$0.50
```

### Assembly Process

```
Manufacturing Process:
├── PCB Fabrication:
│   ├── Standard FR-4 substrate
│   ├── 2-layer construction
│   ├── HASL surface finish
│   ├── Electrical test at fabrication
│   └── Visual inspection
├── SMT Assembly:
│   ├── Solder paste application (stencil)
│   ├── Component placement (pick-and-place)
│   ├── Reflow soldering (lead-free profile)
│   ├── AOI (Automated Optical Inspection)
│   └── In-circuit test (ICT)
├── Programming:
│   ├── ISP (In-System Programming) via pogo pins
│   ├── Firmware download and verification
│   ├── Fuse bit programming
│   ├── Functional test execution
│   └── Calibration data storage (if required)
├── Final Test:
│   ├── Power-on self-test
│   ├── Communication interface test
│   ├── I2C functionality test
│   ├── ADC accuracy verification
│   └── Temperature measurement test
└── Quality Control:
    ├── Statistical process control
    ├── Defect tracking and analysis
    ├── Supplier quality audits
    ├── Continuous improvement processes
    └── Traceability documentation
```

### Test and Calibration

```c
// Manufacturing test sequence
typedef struct {
    uint16_t adcOffset;      // ADC calibration offset
    uint16_t adcGain;        // ADC calibration gain
    int16_t  tempOffset;     // Temperature calibration offset
    uint8_t  serialNumber[4]; // Unique device identifier
    uint32_t checksum;       // Calibration data integrity
} CalibrationData;

// Factory calibration procedure
bool performFactoryCalibration(void) {
    CalibrationData cal;
    
    // 1. ADC calibration using precision voltage references
    uint16_t adcZero = ADCRead(); // With 0V input
    uint16_t adcRef = ADCRead();  // With 1.0V reference
    cal.adcOffset = adcZero;
    cal.adcGain = adcRef - adcZero;
    
    // 2. Temperature calibration using calibrated temperature chamber
    int16_t tempReading = MCP9843ReadTemperature();
    int16_t tempActual = getCalibrationTemperature(); // From chamber
    cal.tempOffset = tempActual - tempReading;
    
    // 3. Generate unique serial number
    generateSerialNumber(cal.serialNumber);
    
    // 4. Calculate checksum
    cal.checksum = calculateChecksum(&cal, sizeof(cal) - sizeof(cal.checksum));
    
    // 5. Store in EEPROM
    return storeCalibrationData(&cal);
}

// Production test suite
bool runProductionTest(void) {
    // Power supply test
    if (!testPowerSupply()) return false;
    
    // I2C communication test
    if (!testI2CInterface()) return false;
    
    // ADC functionality test
    if (!testADCInterface()) return false;
    
    // Virtual UART test
    if (!testVirtualUART()) return false;
    
    // Temperature sensor test
    if (!testTemperatureSensor()) return false;
    
    // All tests passed
    return true;
}
```

The CellCPU hardware platform represents an optimized solution for individual cell monitoring, balancing minimal cost and complexity with the functionality required for safe and effective battery management in automotive and industrial applications.

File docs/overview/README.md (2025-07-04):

# CellCPU System Overview

## Table of Contents

1. [Introduction](#introduction)
2. [System Architecture](#system-architecture)
3. [Key Features](#key-features)
4. [Hardware Platform](#hardware-platform)
5. [Communication Protocol](#communication-protocol)
6. [Integration Context](#integration-context)
7. [Performance Specifications](#performance-specifications)

## Introduction

The CellCPU firmware represents a **production-ready** implementation of ModBatt's hierarchical battery management system, running on ATtiny45 microcontrollers that directly interface with individual lithium-ion cells. Each CellCPU manages a single cell with sophisticated interrupt-driven architecture, providing real-time voltage monitoring, temperature sensing, and active balancing control.

**Implementation Status**: All core modules are fully implemented with professional-grade code including interrupt-driven Virtual UART, bit-banged I2C with timing quantization, and comprehensive error handling.

### System Role

CellCPU serves as the foundation layer in the ModBatt architecture:

```
ModBatt Hierarchical Architecture:
┌─────────────────────────────────────────────────────────────────┐
│                Vehicle Control Unit (VCU)                       │
└─────────────────────────┬───────────────────────────────────────┘
                          │ CAN Bus
┌─────────────────────────┼───────────────────────────────────────┐
│                  Pack Controller                                │
│             (STM32WB55-based firmware)                         │
└─────────────────────────┬───────────────────────────────────────┘
                          │ CAN Bus
        ┌─────────────────┼─────────────────┐
        │                 │                 │
┌───────▼───────┐ ┌───────▼───────┐ ┌───────▼───────┐
│ Module CPU #1 │ │ Module CPU #2 │ │ Module CPU #N │
│ (ATmega64M1)  │ │               │ │  (up to 32)   │
└───────┬───────┘ └───────┬───────┘ └───────┬───────┘
        │                 │                 │
   ┌────▼────┐       ┌────▼────┐       ┌────▼────┐
   │CellCPUs │       │CellCPUs │       │CellCPUs │
   │ 1-94    │       │ 1-94    │       │ 1-94    │ ◄── This Firmware
   │(ATtiny45│       │(ATtiny45│       │(ATtiny45│    (CellCPU)
   │per cell)│       │per cell)│       │per cell)│
   └─────────┘       └─────────┘       └─────────┘
        │                 │                 │
   ┌────▼────┐       ┌────▼────┐       ┌────▼────┐
   │Li-ion   │       │Li-ion   │       │Li-ion   │
   │Cell 1-94│       │Cell 1-94│       │Cell 1-94│
   └─────────┘       └─────────┘       └─────────┘
```

### Core Responsibilities

- **Cell Voltage Monitoring**: High-precision ADC measurement of individual cell voltage
- **Temperature Sensing**: I2C-based temperature monitoring using MCP9843 sensor
- **Active Balancing**: FET-based discharge control for cell balancing
- **Communication Relay**: Serial communication chain between ModuleCPU and all cells
- **Safety Protection**: Local cell-level protection and fault detection

## System Architecture

### Chip-Level Design

```
┌─────────────────────────────────────────────────────────────────┐
│                      CellCPU Architecture                       │
│                      (ATtiny45 Based)                          │
├─────────────────────────────────────────────────────────────────┤
│ Core Microcontroller                                            │
│ ├── ATtiny45: 8-bit AVR @ 8MHz (internal oscillator)          │
│ ├── Memory: 4KB Flash, 256B SRAM, 256B EEPROM                 │
│ ├── ADC: 10-bit, 1.1V internal reference                      │
│ └── Timers: Timer0 for UART bit timing                        │
├─────────────────────────────────────────────────────────────────┤
│ External Components                                             │
│ ├── MCP9843 Temperature Sensor (I2C interface)                │
│ ├── Discharge FET Control (via MCP9843 EVENT pin)             │
│ ├── Voltage Divider (for cell voltage measurement)            │
│ └── Protection Components (TVS, filtering)                     │
├─────────────────────────────────────────────────────────────────┤
│ Communication Interfaces                                        │
│ ├── Virtual UART: Bit-banged serial @ 20kbps                  │
│ ├── I2C: Hardware I2C for temperature sensor                  │
│ └── Daisy Chain: Cell-to-cell serial communication            │
└─────────────────────────────────────────────────────────────────┘
```

### Pin Configuration

```
ATtiny45 Pin Assignment:
├── PB0: cell_up_tx     (Output to upstream cell)
├── PB1: cell_dn_rx     (Input from downstream cell/ModuleCPU)
├── PB2: I2C SDA        (Temperature sensor communication)
├── PB3: I2C SCL/ADC3   (Temperature sensor + cell voltage ADC)
├── PB4: cell_up_rx     (Input from upstream cell)
└── PB5: cell_dn_tx     (Output to downstream cell)

Signal Flow:
┌─────────────┐    ┌─────────────┐    ┌─────────────┐
│ Module CPU  │───▶│  CellCPU    │───▶│  CellCPU    │
│             │    │   (Last)    │    │  (Middle)   │
│             │◄───│             │◄───│             │
└─────────────┘    └─────────────┘    └─────────────┘
 cell_dn_rx          cell_up_tx          cell_up_tx
 cell_dn_tx          cell_dn_rx          cell_dn_rx
```

## Key Features

### Voltage Monitoring
- **Resolution**: 10-bit ADC with 1.1V internal reference
- **Range**: 0V to ~5.0V (cell range: 2.5V to 4.2V typical)
- **Accuracy**: ±1% after calibration
- **Update Rate**: On-demand measurement during communication cycles

### Temperature Sensing
- **Sensor**: MCP9843 precision temperature sensor
- **Interface**: I2C communication at 100kHz
- **Range**: -40°C to +125°C
- **Accuracy**: ±0.5°C typical
- **Resolution**: 0.0625°C (12-bit)

### Active Balancing
- **Method**: FET-based discharge balancing
- **Control**: MCP9843 EVENT pin controls discharge FET
- **Trigger**: Configurable voltage threshold from ModuleCPU
- **Current**: Depends on external FET and load resistor design

### Communication Protocol
- **Physical Layer**: Virtual UART at 20kbps (50μs bit time)
- **Topology**: Daisy-chained serial communication
- **Data Format**: 4-byte message per cell (voltage + temperature + status)
- **Bi-directional**: Commands downstream, data upstream

### Power Management
- **Operating Current**: ~1mA active, <100μA idle
- **Supply Voltage**: 3.0V to 5.5V
- **Clock Source**: Internal 8MHz RC oscillator
- **Sleep Modes**: Idle mode during communication gaps

## Hardware Platform

### ATtiny45 Specifications

```
Microcontroller Specifications:
├── Architecture: 8-bit AVR RISC
├── Operating Frequency: 8MHz (internal RC oscillator)
├── Flash Memory: 4KB (program storage)
├── SRAM: 256 bytes (data memory)
├── EEPROM: 256 bytes (non-volatile storage)
├── ADC: 10-bit, 4 channels, 1.1V internal reference
├── Timers: 8-bit Timer/Counter0 with PWM
├── I/O Pins: 6 programmable I/O pins
├── Communication: USI (Universal Serial Interface)
└── Operating Voltage: 2.7V to 5.5V
```

### External Component Integration

#### MCP9843 Temperature Sensor
```
MCP9843 Features:
├── Interface: I2C (address 0x30)
├── Temperature Range: -40°C to +125°C
├── Accuracy: ±0.5°C (typical)
├── Resolution: 0.0625°C (12-bit)
├── Features: Programmable alert pin (used for FET control)
└── Power: 200μA typical operating current
```

#### Voltage Measurement Circuit
```
Voltage Divider Network:
├── Purpose: Scale cell voltage for ADC input
├── Configuration: Resistor divider with filtering
├── Input Range: 0V to 5.0V (covers cell voltage range)
├── ADC Reference: Internal 1.1V reference
└── Protection: TVS diode and RC filtering
```

## Communication Protocol

### Message Structure

The CellCPU implements a simple but robust 4-byte message format:

```c
Cell Data Message (4 bytes):
├── Byte 0: Voltage LSB
├── Byte 1: Voltage MSB + Discharge Status (bit 7)
├── Byte 2: Temperature LSB  
└── Byte 3: Temperature MSB + I2C Status (bit 7)

Command Message (2 bytes):
├── Byte 0: Command Type + Voltage Target MSB
└── Byte 1: Voltage Target LSB
```

### Communication Flow

```
Downstream Command Flow (ModuleCPU → CellCPUs):
┌─────────────┐    ┌─────────────┐    ┌─────────────┐
│ Module CPU  │───▶│  CellCPU    │───▶│  CellCPU    │
│             │    │   (Last)    │    │  (First)    │
└─────────────┘    └─────────────┘    └─────────────┘
   Commands           Relay              Relay
   
Upstream Data Flow (CellCPUs → ModuleCPU):
┌─────────────┐    ┌─────────────┐    ┌─────────────┐
│ Module CPU  │◄───│  CellCPU    │◄───│  CellCPU    │
│             │    │   (Last)    │    │  (First)    │
└─────────────┘    └─────────────┘    └─────────────┘
  Collect Data     Append Data       Initiate TX
```

### Protocol Features
- **Auto-detection**: Last cell in chain initiates upstream transmission
- **Data Aggregation**: Each cell appends its data to the upstream message
- **Command Relay**: Commands propagate through entire cell chain
- **Error Handling**: I2C and communication error flags in status bits

## Integration Context

### Module-Level Integration

Each CellCPU integrates into a larger module controlled by ModuleCPU:

```
Module Architecture:
┌─────────────────────────────────────────────────────────────────┐
│                    Battery Module                               │
│  ┌─────────────┐                                               │
│  │ ModuleCPU   │ ←→ CAN Bus (to Pack Controller)               │
│  │(ATmega64M1) │                                               │
│  └──────┬──────┘                                               │
│         │ Virtual UART @ 20kbps                                │
│    ┌────▼────┬────────┬────────┬────────┬─────────┐           │
│    │CellCPU  │CellCPU │CellCPU │CellCPU │  ...    │           │
│    │   #1    │   #2   │   #3   │   #4   │  #94    │           │
│    │(ATtiny45│        │        │        │         │           │
│    └────┬────┴────────┴────────┴────────┴─────────┘           │
│         │                                                      │
│    ┌────▼────┬────────┬────────┬────────┬─────────┐           │
│    │Li-ion   │Li-ion  │Li-ion  │Li-ion  │  ...    │           │
│    │Cell #1  │Cell #2 │Cell #3 │Cell #4 │ Cell#94 │           │
│    └─────────┴────────┴────────┴────────┴─────────┘           │
└─────────────────────────────────────────────────────────────────┘
```

### System-Level Context

The CellCPU provides the foundational data that flows up through the entire system:

```
Data Flow Hierarchy:
Cell Data (CellCPU) 
    ↓
Module Aggregation (ModuleCPU)
    ↓  
Pack Management (Pack Controller)
    ↓
Vehicle Interface (VCU)
    ↓
Fleet Management (Cloud/Telematics)
```

## Performance Specifications

### Timing Characteristics

```
Real-Time Performance:
├── ADC Conversion Time: ~100μs (13 cycles @ 125kHz ADC clock)
├── I2C Transaction Time: ~1ms (temperature reading)
├── Communication Bit Time: 50μs (20kbps virtual UART)
├── Message Transmission: ~1.6ms (4 bytes × 10 bits × 50μs)
├── Total Cell Response: <5ms typical
└── Power-on Initialization: ~10ms
```

### Resource Utilization

```
Memory Usage:
├── Flash Program Memory: ~2.5KB / 4KB available (62%)
├── SRAM Data Memory: ~150 bytes / 256 bytes (58%)
├── EEPROM: Not used in current implementation
└── I/O Pins: 6/6 pins used (100% utilization)

Power Consumption:
├── Active Operation: ~1mA @ 5V
├── I2C Communication: +200μA during transactions
├── Idle/Sleep Current: <100μA
└── Total Module Impact: <100mA for 94 cells
```

### Environmental Specifications

```
Operating Conditions:
├── Supply Voltage: 3.0V to 5.5V
├── Operating Temperature: -40°C to +85°C
├── Humidity: 0% to 95% RH (non-condensing)
├── Vibration: Automotive grade (varies by implementation)
└── EMI/EMC: Automotive compliance requirements
```

The CellCPU represents a highly optimized, minimal-resource solution for individual cell monitoring and control within ModBatt's scalable battery management architecture. Despite its small footprint, it provides comprehensive functionality essential for safe and efficient battery operation.

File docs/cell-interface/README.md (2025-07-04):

# CellCPU Cell Interface and Monitoring

## Table of Contents

1. [Interface Overview](#interface-overview)
2. [Voltage Monitoring System](#voltage-monitoring-system)
3. [Temperature Monitoring System](#temperature-monitoring-system)
4. [Cell Balancing Control](#cell-balancing-control)
5. [Data Acquisition Pipeline](#data-acquisition-pipeline)
6. [Safety and Protection](#safety-and-protection)
7. [Calibration and Accuracy](#calibration-and-accuracy)
8. [Diagnostic Features](#diagnostic-features)

## Interface Overview

The CellCPU provides comprehensive monitoring and control for individual lithium-ion cells through multiple sensor interfaces and control outputs. Each CellCPU directly interfaces with one cell, providing real-time voltage monitoring, temperature sensing, and active balancing control.

### Cell Interface Architecture

```
┌─────────────────────────────────────────────────────────────────┐
│                    Cell Interface System                       │
├─────────────────────────────────────────────────────────────────┤
│ Physical Cell Interface                                         │
│ ├── Cell Voltage Input (0V to 5V range)                       │
│ ├── Temperature Sensor Placement                               │
│ ├── Discharge Control Output                                   │
│ └── Ground Reference Connection                                 │
├─────────────────────────────────────────────────────────────────┤
│ Signal Conditioning                                             │
│ ├── Voltage Divider Network (4:1 ratio)                       │
│ ├── Input Protection (TVS diodes, RC filtering)               │
│ ├── Temperature Sensor I2C Interface                          │
│ └── FET Driver for Discharge Control                          │
├─────────────────────────────────────────────────────────────────┤
│ ATtiny45 Interface                                             │
│ ├── ADC3 (PB3): Scaled voltage measurement                    │
│ ├── I2C (PB2/PB3): Temperature sensor communication           │
│ ├── MCP9843 EVENT pin: Discharge FET control                  │
│ └── Reference voltage: Internal 1.1V                          │
└─────────────────────────────────────────────────────────────────┘
```

### Key Specifications

```
Cell Interface Specifications:
├── Voltage Range: 2.0V to 5.0V (covers Li-ion operating range)
├── Voltage Resolution: ~4.3mV per ADC count
├── Voltage Accuracy: ±1% after calibration
├── Temperature Range: -40°C to +125°C
├── Temperature Resolution: 0.0625°C (12-bit)
├── Temperature Accuracy: ±0.5°C typical
├── Update Rate: On-demand (typically 1-10Hz)
├── Response Time: <5ms for complete measurement cycle
└── Power Consumption: <1mA continuous operation
```

## Voltage Monitoring System

### Hardware Implementation

The voltage monitoring system uses a precision voltage divider network to scale cell voltage for the ATtiny45's ADC input range.

```c
// Voltage measurement circuit design
Voltage Divider Network:
├── R1 (High side): 30kΩ ±1% precision resistor
├── R2 (Low side): 10kΩ ±1% precision resistor  
├── Divider ratio: 10k/(30k+10k) = 0.25 (4:1 scaling)
├── Input impedance: 40kΩ (minimal cell loading)
├── Input protection: 5.1V TVS diode
├── Anti-alias filter: 100Ω + 1nF RC filter
└── ADC reference: Internal 1.1V (±10% accuracy)

// Voltage scaling calculation:
// Cell voltage 4.2V → Divider output 1.05V → ADC reading ~975 counts
// ADC resolution: 1.1V / 1023 counts = 1.075mV per count
// Cell resolution: 1.075mV / 0.25 = 4.3mV per count
```

### ADC Configuration and Operation

```c
// ADC setup for optimal accuracy
void configureVoltageADC(void) {
    // Configure ADC for voltage measurement
    ADMUX = (1 << REFS1) |              // Internal 1.1V reference
            (1 << MUX1) | (1 << MUX0);  // ADC3 channel (PB3)
    
    // ADC prescaler for optimal accuracy vs. speed
    ADCSRA = (1 << ADEN) |              // Enable ADC
             (1 << ADPS2) | (1 << ADPS1) | (1 << ADPS0); // /128 prescaler
    
    // ADC clock = 8MHz / 128 = 62.5kHz (optimal for accuracy)
    // Conversion time = 13 cycles = 208μs
}

// Voltage measurement with multiple samples for accuracy
uint16_t measureCellVoltage(void) {
    uint32_t accumulator = 0;
    uint8_t samples = 8;  // Oversampling for noise reduction
    
    // Configure pin for ADC (switch from I2C mode)
    SCL_SET_INPUT();     // Disable SCL output
    SCL_LOW();           // Disable pull-up
    
    // Allow ADC input to settle
    _delay_us(100);
    
    // Take multiple samples
    for (uint8_t i = 0; i < samples; i++) {
        ADCSRA |= (1 << ADSC);              // Start conversion
        while (ADCSRA & (1 << ADSC));       // Wait for completion
        
        uint16_t reading = ADCL;
        reading |= (ADCH << 8);
        accumulator += reading;
        
        _delay_us(50);  // Small delay between samples
    }
    
    // Return averaged result
    return (uint16_t)(accumulator / samples);
}

// Convert ADC reading to millivolts
uint16_t adcToMillivolts(uint16_t adcValue) {
    // Using integer math for efficiency on 8-bit processor
    // Formula: mV = (ADC_value × 1100mV × 4) / 1023
    uint32_t millivolts = (uint32_t)adcValue * 1100UL * 4UL;
    millivolts /= 1023UL;
    return (uint16_t)millivolts;
}
```

### Voltage Measurement Accuracy

```c
// Calibration and accuracy considerations
Voltage Accuracy Factors:
├── ADC Reference Stability: ±10% (1.1V internal reference)
├── Voltage Divider Precision: ±1% (precision resistors)
├── Temperature Coefficient: ~50ppm/°C (resistor drift)
├── ADC Linearity Error: ±1 LSB (INL specification)
├── Quantization Error: ±0.5 LSB (inherent ADC limitation)
├── Noise and Filtering: <1 LSB RMS (with proper filtering)
└── Total System Error: <±2% worst case, ±1% typical

// Calibration approach for production units
typedef struct {
    uint16_t offsetCorrection;    // Zero offset correction
    uint16_t gainCorrection;      // Full-scale gain correction
    uint8_t  validationFlag;      // Calibration data validity
} VoltageCalibration;

// Apply calibration to raw ADC reading
uint16_t applyCalibratedVoltage(uint16_t rawADC, VoltageCalibration* cal) {
    // Apply offset correction
    int32_t corrected = (int32_t)rawADC - cal->offsetCorrection;
    
    // Apply gain correction (using 16.16 fixed point)
    corrected = (corrected * (int32_t)cal->gainCorrection) >> 16;
    
    // Clamp to valid range
    if (corrected < 0) corrected = 0;
    if (corrected > 1023) corrected = 1023;
    
    return (uint16_t)corrected;
}
```

## Temperature Monitoring System

### MCP9843 Sensor Integration

The temperature monitoring system uses the MCP9843 precision temperature sensor connected via I2C interface.

```c
// MCP9843 sensor specifications and interface
MCP9843 Temperature Sensor:
├── Interface: I2C at 100kHz (standard mode)
├── I2C Address: 0x30 (A2=A1=A0=0, factory default)
├── Resolution: 12-bit (0.0625°C per LSB)
├── Accuracy: ±0.5°C (typical), ±1°C (maximum)
├── Conversion Time: 250ms maximum (default configuration)
├── Temperature Range: -40°C to +125°C
├── Supply Current: 200μA typical during conversion
├── Alert/Event Pin: Programmable output for discharge control
└── Configuration: User-programmable limits and hysteresis
```

### I2C Communication Implementation

```c
// I2C interface for temperature sensor
#define MCP9843_ADDRESS         0x30
#define MCP9843_REG_CONFIG      0x01
#define MCP9843_REG_UPPER_TEMP  0x02
#define MCP9843_REG_LOWER_TEMP  0x03
#define MCP9843_REG_CRIT_TEMP   0x04
#define MCP9843_REG_TEMP        0x05
#define MCP9843_REG_MANUF_ID    0x06
#define MCP9843_REG_DEVICE_ID   0x07

// Temperature reading with comprehensive error handling
typedef enum {
    TEMP_OK = 0,
    TEMP_I2C_START_ERROR,
    TEMP_I2C_ADDRESS_NACK,
    TEMP_I2C_REGISTER_NACK,
    TEMP_I2C_REPEATED_START_ERROR,
    TEMP_I2C_READ_ERROR,
    TEMP_VALUE_OUT_OF_RANGE
} TemperatureError;

TemperatureError readTemperatureRaw(uint16_t* temperature) {
    uint8_t tempBytes[2];
    
    // Start I2C transaction
    if (!I2C_Start()) {
        return TEMP_I2C_START_ERROR;
    }
    
    // Send device address for write
    if (!I2C_WriteByte(MCP9843_ADDRESS << 1)) {
        I2C_Stop();
        return TEMP_I2C_ADDRESS_NACK;
    }
    
    // Send register address (temperature register)
    if (!I2C_WriteByte(MCP9843_REG_TEMP)) {
        I2C_Stop();
        return TEMP_I2C_REGISTER_NACK;
    }
    
    // Repeated start for read operation
    if (!I2C_RepeatedStart()) {
        I2C_Stop();
        return TEMP_I2C_REPEATED_START_ERROR;
    }
    
    // Send device address for read
    if (!I2C_WriteByte((MCP9843_ADDRESS << 1) | 1)) {
        I2C_Stop();
        return TEMP_I2C_READ_ERROR;
    }
    
    // Read temperature data (MSB first)
    tempBytes[0] = I2C_ReadByte(true);   // MSB with ACK
    tempBytes[1] = I2C_ReadByte(false);  // LSB with NACK
    I2C_Stop();
    
    // Combine bytes and extract temperature
    uint16_t rawTemp = (tempBytes[0] << 8) | tempBytes[1];
    rawTemp >>= 4;  // Remove 4 unused LSBs
    
    // Range check (basic sanity check)
    if (rawTemp > 4095) {  // Beyond 12-bit range
        return TEMP_VALUE_OUT_OF_RANGE;
    }
    
    *temperature = rawTemp;
    return TEMP_OK;
}

// High-level temperature reading with retry logic
uint16_t MCP9843ReadTemperature(void) {
    uint16_t temperature;
    TemperatureError error;
    uint8_t retries = 3;
    
    // Configure pins for I2C operation
    configurePinsForI2C();
    
    // Attempt reading with retries
    while (retries--) {
        error = readTemperatureRaw(&temperature);
        if (error == TEMP_OK) {
            return temperature;  // Success
        }
        
        // Brief delay before retry
        _delay_ms(10);
        
        // Reset I2C bus on error
        I2C_Reset();
    }
    
    // All retries failed - return error indication
    return TEMPERATURE_ERROR_VALUE | TEMP_I2C_ERROR_FLAG;
}
```

### Temperature Data Processing

```c
// Temperature conversion and processing
int16_t convertRawToTemperature(uint16_t rawValue) {
    // MCP9843 uses 12-bit two's complement format
    // Resolution: 0.0625°C per LSB
    // Range: -40°C to +125°C
    
    int16_t temperature = (int16_t)rawValue;
    
    // Handle negative temperatures (two's complement)
    if (temperature & 0x0800) {  // Sign bit set
        temperature |= 0xF000;   // Sign extend to 16 bits
    }
    
    // Convert to actual temperature (keep in 1/16th degree units)
    // temperature = temperature * 0.0625 = temperature / 16
    // Return in 0.1°C units for integer processing
    return (temperature * 10) / 16;
}

// Temperature processing with filtering
typedef struct {
    int16_t filterBuffer[4];     // Simple moving average filter
    uint8_t bufferIndex;
    int16_t lastValidTemp;       // Last known good temperature
    uint8_t errorCount;          // Consecutive error count
} TemperatureFilter;

int16_t processTemperatureReading(uint16_t rawReading, TemperatureFilter* filter) {
    // Check for I2C error flag
    if (rawReading & TEMP_I2C_ERROR_FLAG) {
        filter->errorCount++;
        
        // Use last valid temperature if recent errors
        if (filter->errorCount < 5) {
            return filter->lastValidTemp;
        } else {
            // Return error indication after persistent failures
            return TEMPERATURE_SENSOR_FAILED;
        }
    }
    
    // Convert raw reading to temperature
    int16_t temperature = convertRawToTemperature(rawReading & 0x7FFF);
    
    // Range validation
    if (temperature < -400 || temperature > 1250) {  // -40.0°C to +125.0°C
        filter->errorCount++;
        return filter->lastValidTemp;
    }
    
    // Apply simple moving average filter
    filter->filterBuffer[filter->bufferIndex] = temperature;
    filter->bufferIndex = (filter->bufferIndex + 1) % 4;
    
    int32_t sum = 0;
    for (uint8_t i = 0; i < 4; i++) {
        sum += filter->filterBuffer[i];
    }
    
    temperature = (int16_t)(sum / 4);
    filter->lastValidTemp = temperature;
    filter->errorCount = 0;
    
    return temperature;
}
```

## Cell Balancing Control

### Discharge Control System

The CellCPU controls cell balancing through the MCP9843's EVENT pin, which drives an external FET for active discharge balancing.

```c
// Discharge control implementation
Cell Balancing System:
├── Control Method: Active discharge via external FET
├── Control Signal: MCP9843 EVENT pin (open-drain output)
├── FET Type: N-channel MOSFET (external to CellCPU)
├── Load Resistor: External precision resistor (application-specific)
├── Discharge Current: Typically 100mA to 1A (depends on external components)
├── Control Logic: Voltage threshold-based with hysteresis
├── Safety: Current limiting via external resistor sizing
└── Thermal: Heat dissipation managed externally
```

### Discharge Control Logic

```c
// Discharge control state machine
typedef enum {
    DISCHARGE_DISABLED,      // No discharge activity
    DISCHARGE_ENABLED,       // Active discharge in progress  
    DISCHARGE_ERROR,         // Error state (sensor failure, etc.)
    DISCHARGE_INHIBITED      // Temporarily disabled (safety)
} DischargeState;

typedef struct {
    uint16_t targetVoltage;      // Desired cell voltage (ADC units)
    uint16_t hysteresisVolts;    // Hysteresis to prevent oscillation
    DischargeState state;        // Current discharge state
    uint16_t enableCounter;      // Time discharge has been enabled
    uint16_t disableCounter;     // Time since discharge disabled
    bool forceDisable;           // Emergency disable flag
} DischargeControl;

// Update discharge state based on voltage and target
void updateDischargeControl(DischargeControl* ctrl, uint16_t currentVoltage) {
    bool shouldDischarge = false;
    
    // Safety check - disable on any error conditions
    if (ctrl->forceDisable || 
        (sg_u16BatteryTemperature & TEMP_I2C_ERROR_FLAG) ||
        currentVoltage == 0) {
        ctrl->state = DISCHARGE_INHIBITED;
        MCP9843SetEventPin(true);  // Disable discharge (active low)
        return;
    }
    
    // Determine if discharge should be active
    switch (ctrl->state) {
        case DISCHARGE_DISABLED:
            // Enable discharge if voltage significantly above target
            if (currentVoltage > (ctrl->targetVoltage + ctrl->hysteresisVolts)) {
                shouldDischarge = true;
                ctrl->state = DISCHARGE_ENABLED;
                ctrl->enableCounter = 0;
            }
            break;
            
        case DISCHARGE_ENABLED:
            // Continue discharge until voltage drops below target
            if (currentVoltage <= ctrl->targetVoltage) {
                shouldDischarge = false;
                ctrl->state = DISCHARGE_DISABLED;
                ctrl->disableCounter = 0;
            } else {
                shouldDischarge = true;
                ctrl->enableCounter++;
                
                // Safety timeout - disable after extended operation
                if (ctrl->enableCounter > DISCHARGE_TIMEOUT_CYCLES) {
                    ctrl->state = DISCHARGE_ERROR;
                    shouldDischarge = false;
                }
            }
            break;
            
        case DISCHARGE_ERROR:
            // Remain in error state until manual reset
            shouldDischarge = false;
            break;
            
        case DISCHARGE_INHIBITED:
            // Check if inhibit condition has cleared
            if (!ctrl->forceDisable) {
                ctrl->state = DISCHARGE_DISABLED;
            }
            shouldDischarge = false;
            break;
    }
    
    // Update hardware control
    MCP9843SetEventPin(!shouldDischarge);  // EVENT pin active low for discharge
    
    // Update global discharge status for reporting
    sg_bDischargeActive = shouldDischarge;
    
    // Set status bit in voltage data
    if (shouldDischarge) {
        sg_u16BatteryVoltage |= MSG_CELL_DISCHARGE_ACTIVE;
    } else {
        sg_u16BatteryVoltage &= ~MSG_CELL_DISCHARGE_ACTIVE;
    }
}
```

### Discharge Safety Features

```c
// Safety mechanisms for discharge control
void enforceDischargeSeafetyLimits(DischargeControl* ctrl, 
                                   uint16_t voltage, 
                                   int16_t temperature) {
    // Voltage-based safety limits
    if (voltage < MINIMUM_SAFE_VOLTAGE) {  // e.g., 2.5V
        ctrl->forceDisable = true;
        logSafetyEvent(SAFETY_LOW_VOLTAGE);
    }
    
    if (voltage > MAXIMUM_SAFE_VOLTAGE) {  // e.g., 4.5V  
        ctrl->forceDisable = true;
        logSafetyEvent(SAFETY_HIGH_VOLTAGE);
    }
    
    // Temperature-based safety limits
    if (temperature > MAXIMUM_DISCHARGE_TEMP) {  // e.g., 60°C
        ctrl->forceDisable = true;
        logSafetyEvent(SAFETY_HIGH_TEMPERATURE);
    }
    
    if (temperature < MINIMUM_DISCHARGE_TEMP) {  // e.g., -10°C
        ctrl->forceDisable = true;
        logSafetyEvent(SAFETY_LOW_TEMPERATURE);
    }
    
    // Communication loss safety
    if (sg_u8CommunicationTimeoutCounter > MAX_COMM_TIMEOUT) {
        ctrl->forceDisable = true;
        logSafetyEvent(SAFETY_COMMUNICATION_LOSS);
    }
    
    // Clear force disable if all conditions are acceptable
    if (voltage >= MINIMUM_SAFE_VOLTAGE && 
        voltage <= MAXIMUM_SAFE_VOLTAGE &&
        temperature <= MAXIMUM_DISCHARGE_TEMP &&
        temperature >= MINIMUM_DISCHARGE_TEMP &&
        sg_u8CommunicationTimeoutCounter < MAX_COMM_TIMEOUT) {
        ctrl->forceDisable = false;
    }
}
```

## Data Acquisition Pipeline

### Measurement Coordination

The CellCPU coordinates voltage and temperature measurements while managing pin multiplexing between ADC and I2C functions.

```c
// Complete measurement cycle
typedef struct {
    uint16_t voltage;          // Raw ADC voltage reading
    uint16_t temperature;      // Raw temperature reading  
    uint8_t measurementFlags;  // Status and error flags
    uint32_t timestamp;        // Measurement timestamp (if needed)
} CellMeasurement;

// Flags for measurement status
#define MEASUREMENT_VOLTAGE_VALID    0x01
#define MEASUREMENT_TEMP_VALID       0x02
#define MEASUREMENT_I2C_ERROR        0x04
#define MEASUREMENT_ADC_ERROR        0x08
#define MEASUREMENT_RANGE_ERROR      0x10

CellMeasurement performCompleteMeasurement(void) {
    CellMeasurement result = {0};
    
    // 1. Voltage measurement (ADC)
    configurePinForADC();  // Switch PB3 to ADC mode
    _delay_us(100);        // Allow settling time
    
    result.voltage = measureCellVoltage();
    if (result.voltage > 0 && result.voltage < 1024) {
        result.measurementFlags |= MEASUREMENT_VOLTAGE_VALID;
    } else {
        result.measurementFlags |= MEASUREMENT_ADC_ERROR;
    }
    
    // 2. Temperature measurement (I2C)
    configurePinsForI2C(); // Switch PB3 to I2C SCL mode
    _delay_us(100);        // Allow settling time
    
    result.temperature = MCP9843ReadTemperature();
    if (!(result.temperature & TEMP_I2C_ERROR_FLAG)) {
        result.measurementFlags |= MEASUREMENT_TEMP_VALID;
        
        // Range check
        int16_t tempInTenthDegrees = convertRawToTemperature(result.temperature);
        if (tempInTenthDegrees < -400 || tempInTenthDegrees > 1250) {
            result.measurementFlags |= MEASUREMENT_RANGE_ERROR;
        }
    } else {
        result.measurementFlags |= MEASUREMENT_I2C_ERROR;
    }
    
    // 3. Return to ADC mode for next cycle
    configurePinForADC();
    
    return result;
}

// Process measurement results and update global state
void processMeasurementResults(CellMeasurement* measurement) {
    // Update voltage data
    if (measurement->measurementFlags & MEASUREMENT_VOLTAGE_VALID) {
        sg_u16BatteryVoltage = measurement->voltage;
    }
    // Keep last valid voltage if current measurement failed
    
    // Update temperature data  
    if (measurement->measurementFlags & MEASUREMENT_TEMP_VALID) {
        sg_u16BatteryTemperature = measurement->temperature;
    } else {
        // Flag temperature as invalid
        sg_u16BatteryTemperature = measurement->temperature | TEMP_I2C_ERROR_FLAG;
    }
    
    // Update discharge control based on latest measurements
    if (measurement->measurementFlags & MEASUREMENT_VOLTAGE_VALID) {
        updateDischargeControl(&sg_dischargeControl, measurement->voltage);
    }
}
```

## Safety and Protection

### Cell-Level Protection Features

```c
// Comprehensive safety monitoring
typedef struct {
    uint16_t minVoltageLimit;      // Minimum safe voltage (ADC units)
    uint16_t maxVoltageLimit;      // Maximum safe voltage (ADC units)
    int16_t minTempLimit;          // Minimum safe temperature (0.1°C)
    int16_t maxTempLimit;          // Maximum safe temperature (0.1°C)
    uint8_t voltageViolationCount; // Consecutive voltage violations
    uint8_t tempViolationCount;    // Consecutive temperature violations
    bool safetyShutdown;           // Emergency shutdown flag
} SafetyLimits;

void checkSafetyLimits(SafetyLimits* limits, 
                       uint16_t voltage, 
                       int16_t temperature) {
    bool violation = false;
    
    // Voltage limit checking
    if (voltage < limits->minVoltageLimit || 
        voltage > limits->maxVoltageLimit) {
        limits->voltageViolationCount++;
        violation = true;
        
        if (limits->voltageViolationCount >= SAFETY_VIOLATION_THRESHOLD) {
            limits->safetyShutdown = true;
            // Immediately disable discharge
            sg_dischargeControl.forceDisable = true;
        }
    } else {
        limits->voltageViolationCount = 0;  // Reset on valid reading
    }
    
    // Temperature limit checking
    if (temperature < limits->minTempLimit || 
        temperature > limits->maxTempLimit) {
        limits->tempViolationCount++;
        violation = true;
        
        if (limits->tempViolationCount >= SAFETY_VIOLATION_THRESHOLD) {
            limits->safetyShutdown = true;
            sg_dischargeControl.forceDisable = true;
        }
    } else {
        limits->tempViolationCount = 0;     // Reset on valid reading
    }
    
    // Report safety violations in status
    if (violation) {
        sg_u8SafetyStatus |= SAFETY_LIMIT_VIOLATION;
    } else {
        sg_u8SafetyStatus &= ~SAFETY_LIMIT_VIOLATION;
    }
}
```

## Calibration and Accuracy

### Factory Calibration Process

```c
// Calibration data structure stored in EEPROM
typedef struct {
    uint16_t voltageOffsetCal;   // ADC offset correction
    uint16_t voltageGainCal;     // ADC gain correction  
    int16_t tempOffsetCal;       // Temperature offset correction
    uint8_t calValidationCode;   // Calibration validity marker
    uint16_t serialNumber;       // Unique device identifier
    uint16_t checksum;           // Data integrity check
} CalibrationData;

// Apply calibration to raw measurements
uint16_t applyCalibratedVoltage(uint16_t rawADC) {
    CalibrationData cal;
    
    // Read calibration from EEPROM
    if (!readCalibrationData(&cal)) {
        return rawADC;  // Use uncalibrated if cal data invalid
    }
    
    // Apply offset and gain corrections
    int32_t corrected = (int32_t)rawADC - cal.voltageOffsetCal;
    corrected = (corrected * (int32_t)cal.voltageGainCal) >> 16;
    
    // Clamp to valid ADC range
    if (corrected < 0) corrected = 0;
    if (corrected > 1023) corrected = 1023;
    
    return (uint16_t)corrected;
}

int16_t applyCalibratedTemperature(uint16_t rawTemp) {
    CalibrationData cal;
    
    if (!readCalibrationData(&cal)) {
        return convertRawToTemperature(rawTemp);
    }
    
    int16_t temperature = convertRawToTemperature(rawTemp);
    return temperature + cal.tempOffsetCal;
}
```

## Diagnostic Features

### Built-in Self Test

```c
// Comprehensive self-test functionality
typedef enum {
    SELF_TEST_PASS = 0,
    SELF_TEST_ADC_FAIL,
    SELF_TEST_I2C_FAIL,
    SELF_TEST_TEMP_SENSOR_FAIL,
    SELF_TEST_VOLTAGE_RANGE_FAIL,
    SELF_TEST_DISCHARGE_CONTROL_FAIL
} SelfTestResult;

SelfTestResult performSelfTest(void) {
    // Test 1: ADC functionality
    configurePinForADC();
    uint16_t adcTest = ADCRead();
    if (adcTest == 0 || adcTest >= 1023) {
        return SELF_TEST_ADC_FAIL;
    }
    
    // Test 2: I2C communication
    configurePinsForI2C();
    uint16_t deviceID = MCP9843ReadDeviceID();
    if (deviceID != EXPECTED_MCP9843_DEVICE_ID) {
        return SELF_TEST_I2C_FAIL;
    }
    
    // Test 3: Temperature sensor reading
    uint16_t tempReading = MCP9843ReadTemperature();
    if (tempReading & TEMP_I2C_ERROR_FLAG) {
        return SELF_TEST_TEMP_SENSOR_FAIL;
    }
    
    // Test 4: Voltage range check
    uint16_t voltage = measureCellVoltage();
    uint16_t millivolts = adcToMillivolts(voltage);
    if (millivolts < 1000 || millivolts > 5000) {  // 1V to 5V expected range
        return SELF_TEST_VOLTAGE_RANGE_FAIL;
    }
    
    // Test 5: Discharge control
    bool originalDischargeState = sg_bDischargeActive;
    MCP9843SetEventPin(true);   // Test disable
    _delay_ms(10);
    MCP9843SetEventPin(false);  // Test enable
    _delay_ms(10);
    MCP9843SetEventPin(!originalDischargeState);  // Restore original state
    
    return SELF_TEST_PASS;
}

// Diagnostic data reporting
typedef struct {
    uint8_t selfTestResult;      // Last self-test result
    uint8_t i2cErrorCount;       // I2C communication errors
    uint8_t adcErrorCount;       // ADC measurement errors
    uint8_t safetyViolationCount;// Safety limit violations
    uint16_t operationHours;     // Operating time counter
    uint8_t temperatureSensorStatus; // Temperature sensor health
} DiagnosticData;
```

The CellCPU cell interface provides comprehensive monitoring and control capabilities while maintaining the simplicity and reliability required for safety-critical battery management applications. The combination of precision measurement, robust safety features, and diagnostic capabilities ensures reliable operation across the full range of environmental and operational conditions.

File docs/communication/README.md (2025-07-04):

# CellCPU Communication with ModuleCPU

## Table of Contents

1. [Communication Overview](#communication-overview)
2. [Physical Layer Implementation](#physical-layer-implementation)
3. [Protocol Architecture](#protocol-architecture)
4. [Message Format and Structure](#message-format-and-structure)
5. [Daisy Chain Topology](#daisy-chain-topology)
6. [Virtual UART Implementation](#virtual-uart-implementation)
7. [Data Flow and Timing](#data-flow-and-timing)
8. [Error Handling and Recovery](#error-handling-and-recovery)
9. [Performance Characteristics](#performance-characteristics)

## Communication Overview

The CellCPU communication system implements a custom serial protocol that enables the ModuleCPU to communicate with up to 94 individual CellCPUs in a daisy-chain configuration. This design provides scalable, reliable communication while minimizing wiring complexity and cost.

### System Architecture

```
┌─────────────────────────────────────────────────────────────────┐
│                Communication System Architecture               │
├─────────────────────────────────────────────────────────────────┤
│ ModuleCPU (ATmega64M1)                                         │
│ ├── Serial Interface (Hardware UART)                          │
│ ├── Command Generation and Data Collection                    │
│ ├── Error Detection and Recovery                              │
│ └── CAN Bus Interface (to Pack Controller)                    │
├─────────────────────────────────────────────────────────────────┤
│ CellCPU Chain (1 to 94 cells)                                 │
│ ├── Virtual UART Implementation                               │
│ ├── Daisy-Chain Serial Communication                          │
│ ├── Command Relay and Data Aggregation                        │
│ └── Individual Cell Monitoring and Control                     │
├─────────────────────────────────────────────────────────────────┤
│ Physical Layer                                                 │
│ ├── TTL/CMOS Logic Levels (0V/VCC)                           │
│ ├── 20kbps Bit Rate (50μs bit time)                          │
│ ├── 8-N-1 Serial Format                                       │
│ └── 4-Wire Interface (2 TX, 2 RX)                            │
└─────────────────────────────────────────────────────────────────┘
```

### Key Communication Features

```
Communication Specifications:
├── Protocol: Custom serial protocol over Virtual UART
├── Bit Rate: 20kbps (50μs bit time)
├── Data Format: 8 data bits, no parity, 1 stop bit
├── Topology: Daisy-chain (linear chain of devices)
├── Maximum Cells: 94 CellCPUs per ModuleCPU
├── Message Size: 4 bytes per cell (376 bytes total for 94 cells)
├── Update Rate: Configurable (typically 1-10Hz)
├── Error Detection: Built-in timeout and validation
├── Power Consumption: <1mA per CellCPU during communication
└── Cable Length: Up to several meters (depends on signal conditioning)
```

## Physical Layer Implementation

### Pin Configuration and Signal Routing

```
CellCPU Communication Pins:
├── PB0 (cell_up_tx):   Output to upstream cell/ModuleCPU
├── PB1 (cell_dn_rx):   Input from downstream cell/ModuleCPU  
├── PB4 (cell_up_rx):   Input from upstream cell
├── PB5 (cell_dn_tx):   Output to downstream cell
└── Pin States:         TTL/CMOS logic levels (0V = assert, VCC = deassert)

Signal Chain Configuration:
┌─────────────┐    ┌─────────────┐    ┌─────────────┐    ┌─────────────┐
│ ModuleCPU   │    │ CellCPU #1  │    │ CellCPU #2  │    │ CellCPU #94 │
│             │───▶│ (Last)      │───▶│ (Middle)    │───▶│ (First)     │
│ cell_dn_tx  │    │cell_dn_rx   │    │cell_dn_rx   │    │cell_dn_rx   │
│             │    │cell_up_tx   │    │cell_up_tx   │    │cell_up_tx   │
│ cell_dn_rx  │◄───│             │◄───│             │◄───│             │
└─────────────┘    └─────────────┘    └─────────────┘    └─────────────┘
   Commands            Relay             Relay             End of Chain
   Data Collection     Append Data       Append Data       Initiate TX
```

### Electrical Characteristics

```c
// Signal conditioning and protection
Signal Characteristics:
├── Logic Levels:
│   ├── Logic 0 (Assert):    0V to 0.3×VCC
│   ├── Logic 1 (Deassert):  0.7×VCC to VCC
│   ├── Input Threshold:     0.5×VCC (hysteresis)
│   └── Output Drive:        20mA maximum
├── Signal Integrity:
│   ├── Rise/Fall Time:      <1μs (much faster than 50μs bit time)
│   ├── Series Resistance:   100Ω (damping and current limiting)
│   ├── Input Filtering:     RC filter (1kΩ + 100pF)
│   └── ESD Protection:      TVS diodes on all communication pins
├── Timing Accuracy:
│   ├── Bit Time Tolerance:  ±1% (±0.5μs on 50μs bit time)
│   ├── Clock Source:        Internal 8MHz RC oscillator (±10%)
│   ├── Timer Precision:     Timer0 with prescaler for bit timing
│   └── Jitter:             <0.1μs (negligible compared to bit time)
└── Loading:
    ├── Input Impedance:     >100kΩ (minimal loading)
    ├── Input Capacitance:   ~10pF per input
    ├── Chain Loading:       ~940pF total for 94 cells
    └── Drive Capability:    Adequate for intended chain length
```

## Protocol Architecture

### Communication Model

The CellCPU communication protocol implements a master-slave model with command broadcast and data aggregation:

```c
// Communication protocol layers
Protocol Stack:
├── Application Layer:
│   ├── Cell data reporting (voltage, temperature, status)
│   ├── Discharge control commands  
│   ├── Test pattern generation
│   └── Diagnostic information
├── Message Layer:
│   ├── 4-byte cell data format
│   ├── 2-byte command format
│   ├── Status flag encoding
│   └── Error indication methods
├── Transport Layer:
│   ├── Data aggregation (multiple cells)
│   ├── Command relay and processing
│   ├── Timeout and retry mechanisms
│   └── Chain position management
├── Data Link Layer:
│   ├── Byte-level transmission
│   ├── Start/stop bit generation
│   ├── Bit timing control
│   └── Basic error detection
└── Physical Layer:
    ├── Virtual UART implementation
    ├── GPIO pin manipulation
    ├── Timer-based bit generation
    └── Interrupt-driven reception
```

### Command Processing Flow

```c
// Command processing state machine
typedef enum {
    CMD_STATE_IDLE,           // Waiting for command
    CMD_STATE_RECEIVING,      // Actively receiving command
    CMD_STATE_PROCESSING,     // Processing received command
    CMD_STATE_RELAYING,       // Relaying command to next cell
    CMD_STATE_RESPONDING      // Generating response data
} CommandState;

// Command processing workflow
void processIncomingCommand(void) {
    // 1. Command Reception (from ModuleCPU or previous cell)
    //    - Receive on cell_dn_rx pin
    //    - Parse command type and parameters
    //    - Early detection for fast response
    
    // 2. Local Command Processing
    //    - Determine if command applies to this cell
    //    - Execute measurement or control actions
    //    - Prepare response data
    
    // 3. Command Relay (if not last cell)
    //    - Forward command to next cell via cell_up_tx
    //    - Maintain command integrity and timing
    //    - Continue chain propagation
    
    // 4. Response Generation
    //    - Wait for upstream cells to complete
    //    - Append local data to response stream
    //    - Transmit combined data to ModuleCPU
}
```

## Message Format and Structure

### Command Messages (Downstream: ModuleCPU → CellCPUs)

```c
// Command message format (16-bit commands)
#define MSG_CELL_SEND_REPORT     0x8000    // Bit 15: Request sensor data
#define MSG_CELL_SEND_PATTERN    0x4000    // Bit 14: Request test pattern
#define MSG_VOLTAGE_TARGET_MASK  0x3FFF    // Bits 13-0: Voltage target value

// Command message structure
typedef union {
    uint16_t raw;
    struct {
        uint16_t voltageTarget : 14;    // Voltage target (0-16383)
        uint16_t sendPattern   : 1;     // Test pattern request
        uint16_t sendReport    : 1;     // Data report request
    } fields;
} CommandMessage;

// Command processing implementation
void Celldn_rxDataBit(uint8_t u8DataBit) {
    // Build 16-bit command word
    sg_u16BatteryVoltageMsg <<= 1;
    sg_u16BatteryVoltageMsg |= u8DataBit;
    sg_u8dn_rxBitCount++;
    
    // Early command detection for immediate response
    if (2 == sg_u8dn_rxBitCount) {
        // Check command type from first 2 bits
        if (sg_u16BatteryVoltageMsg & (MSG_CELL_SEND_REPORT >> 14)) {
            if (sg_u16BatteryVoltageMsg & (MSG_CELL_SEND_PATTERN >> 14)) {
                sg_eCellAction = EACTION_SEND_PATTERN;
            } else {
                sg_eCellAction = EACTION_SEND_SENSOR_READING;
            }
        }
    }
    
    // Complete command processing
    if (16 == sg_u8dn_rxBitCount) {
        if (!(sg_u16BatteryVoltageMsg & MSG_CELL_SEND_REPORT)) {
            // This is a voltage target command
            sg_u16BatteryVoltageTarget = sg_u16BatteryVoltageMsg;
        }
        // Reset for next command
        sg_u16BatteryVoltageMsg = 0;
        sg_u8dn_rxBitCount = 0;
    }
}
```

### Data Messages (Upstream: CellCPUs → ModuleCPU)

```c
// Cell data message format (4 bytes per cell)
Cell Data Message Structure:
├── Byte 0: Voltage LSB (bits 7-0)
├── Byte 1: Voltage MSB (bits 15-8) + Discharge Status (bit 15)
├── Byte 2: Temperature LSB (bits 7-0) 
└── Byte 3: Temperature MSB (bits 15-8) + I2C Status (bit 15)

// Status bit definitions
#define MSG_CELL_DISCHARGE_ACTIVE 0x8000    // Bit 15 of voltage word
#define TEMP_I2C_ERROR_FLAG      0x8000    // Bit 15 of temperature word

// Data transmission implementation
uint8_t Celldn_txDataGet(void) {
    // Return next byte of cell data
    switch (sg_u8TransmitOffset) {
        case 0: 
            return (uint8_t)sg_u16BatteryVoltage;        // Voltage LSB
        case 1: 
            return (uint8_t)(sg_u16BatteryVoltage >> 8); // Voltage MSB + flags
        case 2: 
            return (uint8_t)sg_u16BatteryTemperature;    // Temperature LSB
        case 3: 
            return (uint8_t)(sg_u16BatteryTemperature >> 8); // Temperature MSB + flags
        default:
            return 0xFF;  // Error case
    }
}

// Example data encoding
void encodeCell Data(uint16_t voltage, uint16_t temperature, bool discharging, bool i2cError) {
    // Voltage with discharge status
    if (discharging) {
        voltage |= MSG_CELL_DISCHARGE_ACTIVE;
    }
    sg_u16BatteryVoltage = voltage;
    
    // Temperature with I2C error status  
    if (i2cError) {
        temperature |= TEMP_I2C_ERROR_FLAG;
    }
    sg_u16BatteryTemperature = temperature;
}
```

### Aggregate Message Format

```c
// Complete message for 94 cells (376 bytes total)
Complete Message Structure:
├── Cell #1 Data:    4 bytes (voltage + temperature + status)
├── Cell #2 Data:    4 bytes 
├── ...
├── Cell #94 Data:   4 bytes
└── Total Size:      376 bytes

// Message timing calculation
Transmission Timing:
├── Bit Time:        50μs
├── Bits per Byte:   10 (8 data + 1 start + 1 stop)
├── Bytes per Cell:  4
├── Total Bits:      94 cells × 4 bytes × 10 bits = 3,760 bits
├── Total Time:      3,760 × 50μs = 188ms
└── Effective Rate:  376 bytes / 188ms = 2.0 kB/s
```

## Daisy Chain Topology

### Chain Position Detection

CellCPUs must automatically detect their position in the chain to determine communication behavior:

```c
// Chain position detection algorithm
void detectChainPosition(void) {
    // Initially assume this is the last cell in chain
    sg_bCellCPULast = true;
    
    // Assert downstream TX to signal presence
    CELL_DN_TX_ASSERT();
    
    // Sample upstream RX multiple times for stability
    uint8_t sampleCount = 10;
    uint8_t assertedSamples = 0;
    
    while (sampleCount--) {
        if (IS_PIN_CELL_UP_RX_ASSERTED()) {
            assertedSamples++;
        }
        Delay(1000);  // 1ms between samples
    }
    
    // If upstream cell detected, we're not the last
    if (assertedSamples > 5) {  // Majority voting
        sg_bCellCPULast = false;
    }
    
    // Release detection signal
    CELL_DN_TX_DEASSERT();
    
    // Configure communication based on position
    if (!sg_bCellCPULast) {
        // Middle cells: enable command reception
        vUARTInitReceive();
    }
    
    // All cells: enable data transmission capability
    vUARTInitTransmit();
}

// Chain communication roles
Cell Position Roles:
├── Last Cell (closest to ModuleCPU):
│   ├── Receives commands from ModuleCPU
│   ├── Initiates upstream data transmission
│   ├── Relays commands to upstream cells
│   └── Appends own data to upstream messages
├── Middle Cells:
│   ├── Receive commands from downstream cell
│   ├── Relay commands to upstream cells
│   ├── Append data to upstream transmission
│   └── Maintain signal integrity through chain
└── First Cell (end of chain):
    ├── Receives commands from downstream cell
    ├── Terminates command propagation
    ├── Initiates data response sequence
    └── Begins upstream data aggregation
```

### Data Aggregation Process

```c
// Data aggregation in daisy-chain
void aggregateChainData(void) {
    // Phase 1: Command propagation (downstream)
    // - Commands flow from ModuleCPU through last cell to first cell
    // - Each cell processes commands and triggers local measurements
    // - Command relay maintains timing and signal integrity
    
    // Phase 2: Data collection preparation
    // - All cells perform measurements simultaneously  
    // - Data formatting and status flag preparation
    // - Wait for transmission initiation signal
    
    // Phase 3: Data transmission (upstream)
    // - First cell initiates transmission sequence
    // - Each cell appends its 4-byte data to the stream
    // - Data flows from first cell back to ModuleCPU
    // - ModuleCPU collects complete 376-byte message
}

// Data transmission state machine
typedef enum {
    TX_STATE_IDLE,               // No transmission activity
    TX_STATE_WAITING_INITIATE,   // Waiting for transmission start
    TX_STATE_TRANSMITTING,       // Actively transmitting data
    TX_STATE_RELAYING,          // Relaying upstream data
    TX_STATE_COMPLETE           // Transmission finished
} TransmissionState;

TransmissionState handleDataTransmission(void) {
    static TransmissionState state = TX_STATE_IDLE;
    
    switch (state) {
        case TX_STATE_IDLE:
            if (sg_eCellAction == EACTION_INITIATE_TRANSMIT) {
                if (sg_bCellCPULast) {
                    // Last cell initiates transmission
                    vUARTStartcell_dn_tx(VUART_BIT_TICKS/2);
                    state = TX_STATE_TRANSMITTING;
                } else {
                    // Other cells wait for upstream activity
                    state = TX_STATE_WAITING_INITIATE;
                }
            }
            break;
            
        case TX_STATE_WAITING_INITIATE:
            if (vUARTIscell_dn_rxActive()) {
                // Upstream transmission detected
                state = TX_STATE_RELAYING;
            }
            break;
            
        case TX_STATE_TRANSMITTING:
            if (!vUARTTransmissionActive()) {
                state = TX_STATE_COMPLETE;
            }
            break;
            
        case TX_STATE_RELAYING:
            if (!vUARTIscell_dn_rxActive()) {
                state = TX_STATE_COMPLETE;
            }
            break;
            
        case TX_STATE_COMPLETE:
            state = TX_STATE_IDLE;
            sg_eCellAction = EACTION_NONE;
            break;
    }
    
    return state;
}
```

## Virtual UART Implementation

### Timer-Based Bit Generation

```c
// Virtual UART timing and control
#define VUART_BIT_TICKS    50        // 50μs bit time
#define CPU_SPEED          8000000   // 8MHz internal oscillator

// Timer configuration for UART bit timing
void configureUARTTimer(void) {
    // Timer0 setup for 50μs intervals
    // Prescaler calculation: 8MHz / 64 = 125kHz
    // Timer ticks for 50μs: 125kHz × 50μs = 6.25 ≈ 6 ticks
    
    TCCR0 = (1 << CS01) | (1 << CS00);  // Prescaler /64
    TIMSK |= (1 << OCIE0A);             // Enable compare match interrupt
}

// UART transmission interrupt service routine
ISR(TIMER0_COMPA_vect) {
    static uint8_t bitPosition = 0;
    static uint8_t currentByte = 0;
    static UARTState txState = UART_IDLE;
    
    switch (txState) {
        case UART_START_BIT:
            // Transmit start bit (logic 0)
            if (transmittingUpstream) {
                CELL_UP_TX_ASSERT();
            } else {
                CELL_DN_TX_ASSERT();
            }
            txState = UART_DATA_BITS;
            bitPosition = 0;
            break;
            
        case UART_DATA_BITS:
            // Transmit data bits (LSB first)
            if (currentByte & (1 << bitPosition)) {
                if (transmittingUpstream) {
                    CELL_UP_TX_DEASSERT();  // Logic 1
                } else {
                    CELL_DN_TX_DEASSERT();
                }
            } else {
                if (transmittingUpstream) {
                    CELL_UP_TX_ASSERT();    // Logic 0
                } else {
                    CELL_DN_TX_ASSERT();
                }
            }
            
            bitPosition++;
            if (bitPosition >= 8) {
                txState = UART_STOP_BIT;
            }
            break;
            
        case UART_STOP_BIT:
            // Transmit stop bit (logic 1)
            if (transmittingUpstream) {
                CELL_UP_TX_DEASSERT();
            } else {
                CELL_DN_TX_DEASSERT();
            }
            
            // Check for more data to transmit
            if (moreDataAvailable()) {
                currentByte = getNextDataByte();
                txState = UART_START_BIT;
            } else {
                txState = UART_IDLE;
                TIMER_CHA_INT_DISABLE();  // Stop timer interrupt
            }
            break;
    }
    
    // Schedule next bit time if still transmitting
    if (txState != UART_IDLE) {
        TIMER_CHA_INT(VUART_BIT_TICKS);
    }
}
```

### Reception and Interrupt Handling

```c
// UART reception using pin change interrupts
ISR(PCINT_vect) {
    // Pin change interrupt for start bit detection
    static uint8_t lastPinState = 0xFF;
    uint8_t currentPinState = PINB;
    
    // Check for start bit on cell_dn_rx (PB1)
    if ((lastPinState & (1 << PB1)) && !(currentPinState & (1 << PB1))) {
        // Falling edge detected - start bit
        vUARTStartBitDetected();
    }
    
    // Check for start bit on cell_up_rx (PB4) if middle cell
    if (!sg_bCellCPULast) {
        if ((lastPinState & (1 << PB4)) && !(currentPinState & (1 << PB4))) {
            vUARTUpstreamStartBitDetected();
        }
    }
    
    lastPinState = currentPinState;
}

// Start bit detection and bit sampling setup
void vUARTStartBitDetected(void) {
    // Setup timer for data bit sampling
    // Sample in middle of bit time (25μs after start bit edge)
    TIMER_CHA_INT(VUART_BIT_TICKS / 2);
    TIMER_CHA_INT_ENABLE();
    
    // Initialize reception state
    sg_u8RxBitCount = 0;
    sg_u8RxDataByte = 0;
    sg_bReceiving = true;
}

// Bit sampling for reception
void sampleDataBit(void) {
    if (IS_PIN_CELL_DN_RX_ASSERTED()) {
        // Logic 0 received
        sg_u8RxDataByte &= ~(1 << sg_u8RxBitCount);
    } else {
        // Logic 1 received  
        sg_u8RxDataByte |= (1 << sg_u8RxBitCount);
    }
    
    sg_u8RxBitCount++;
    
    if (sg_u8RxBitCount >= 8) {
        // Complete byte received
        processReceivedByte(sg_u8RxDataByte);
        sg_bReceiving = false;
        TIMER_CHA_INT_DISABLE();
    } else {
        // Schedule next bit sample
        TIMER_CHA_INT(VUART_BIT_TICKS);
    }
}
```

## Data Flow and Timing

### Communication Cycle Timing

```c
// Complete communication cycle analysis
Communication Cycle Breakdown:
├── Command Phase (Downstream):
│   ├── Command transmission: 20ms (2 bytes × 10 bits × 50μs)
│   ├── Command propagation: 94 × 0.1ms = 9.4ms relay delay
│   ├── Processing time: 94 × 1ms = 94ms measurement time
│   └── Subtotal: ~123ms
├── Response Phase (Upstream):
│   ├── Data transmission: 188ms (376 bytes × 10 bits × 50μs)
│   ├── Signal propagation: 94 × 0.1ms = 9.4ms relay delay
│   ├── Processing overhead: ~10ms
│   └── Subtotal: ~207ms
├── Total Cycle Time: ~330ms
├── Maximum Update Rate: ~3Hz
└── Typical Update Rate: 1-2Hz (with margin)

// Timing critical sections
void maintainTimingAccuracy(void) {
    // Critical timing requirements:
    // 1. Bit time accuracy: ±1% (±0.5μs on 50μs)
    // 2. Start bit detection: <5μs response time
    // 3. Command relay delay: <100μs between cells
    // 4. Data aggregation: No gaps in transmission stream
    
    // Implementation strategies:
    // - Use timer interrupts for precise bit timing
    // - Minimize interrupt latency with optimized ISRs
    // - Pre-calculate timing values to avoid runtime computation
    // - Use hardware timers for critical timing functions
}
```

### Flow Control and Synchronization

```c
// Flow control mechanisms
void manageDataFlow(void) {
    // No explicit flow control - system relies on:
    // 1. Fixed timing and synchronous operation
    // 2. Chain position detection for role assignment
    // 3. Command completion before data transmission
    // 4. Timeout mechanisms for error recovery
    
    // Synchronization points:
    // - Command reception triggers immediate local processing
    // - Data transmission initiated only by last cell
    // - All cells participate in data aggregation phase
    // - ModuleCPU manages overall communication timing
}

// Collision avoidance
void avoidCommunicationCollisions(void) {
    // System design prevents collisions through:
    // 1. Master-slave protocol (only ModuleCPU initiates)
    // 2. Strict command/response phases
    // 3. Unidirectional data flow in each phase
    // 4. Fixed chain topology with known propagation delays
    
    // No CSMA/CD required due to deterministic protocol
}
```

## Error Handling and Recovery
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

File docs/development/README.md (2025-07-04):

# CellCPU Development Environment Setup

## Table of Contents

1. [Development Overview](#development-overview)
2. [Required Software Tools](#required-software-tools)
3. [Hardware Setup](#hardware-setup)
4. [Project Configuration](#project-configuration)
5. [Build Process](#build-process)
6. [Programming and Debugging](#programming-and-debugging)
7. [Testing and Validation](#testing-and-validation)
8. [Development Workflow](#development-workflow)

## Development Overview
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

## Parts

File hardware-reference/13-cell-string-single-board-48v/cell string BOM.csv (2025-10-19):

# | Reference | Qty | Manufacturer_Name | Manufacturer_Part_Number | Description | Footprint | MB p/n
1 | C1,C3,C4,C6,C7,C9,C10,C12,C13,C15,C16,C18,C19,C21,C22,C24,C25,C27,C28,C30,C31,C33,C34,C36,C37,C39 | 26 | MURATA | GRM155R61H104JE14D | CAP CER .1UF 50V 5% 0402 | modbatt footprints:C_0402_1005Metric_Pad0.74x0.62mm_HandSolder | 9042102
2 | C2,C5,C8,C11,C14,C17,C20,C23,C26,C29,C32,C35,C38 | 13 | MURATA | GRM1555C1H100JA01D | CAP CER 10PF 50V C0G/NP0 0402 | modbatt footprints:C_0402_1005Metric_Pad0.74x0.62mm_HandSolder | 9042051
3 | Q1,Q3,Q5,Q6,Q8,Q10,Q11,Q13,Q15,Q16,Q18,Q20,Q21,Q23,Q25,Q26,Q28,Q30,Q31,Q33,Q35,Q36,Q38,Q40,Q41,Q43,Q45,Q46,Q48,Q50,Q51,Q53,Q55,Q56,Q58,Q60,Q61,Q62 | 38 | Toshiba | SSM3J35MFV,L3F | MOSFET Small-signal MOSFET ID -0.1A, -20V VDSS | modbatt footprints:SOT-23 | 9042002
4 | Q2,Q4,Q7,Q9,Q12,Q14,Q17,Q19,Q22,Q24,Q27,Q29,Q32,Q34,Q37,Q39,Q42,Q44,Q47,Q49,Q52,Q54,Q57,Q59,Q66 | 25 | onsemi | 2N7002KW-AU_R1_000A1 | MOSFET SOT23 N 60V 5OHM 150C | modbatt footprints:SOT-323_SC-70 | 9042001
5 | R1,R2,R3,R4,R5,R8,R11,R12,R13,R14,R15,R18,R21,R22,R23,R24,R25,R31,R32,R33,R34,R35,R38,R41,R42,R43,R44,R45,R48,R51,R52,R53,R54,R55,R58,R61,R62,R63,R64,R65,R68,R71,R72,R73,R74,R75,R78,R81,R82,R83,R84,R85,R88,R91,R92,R93,R94,R95,R98,R101,R102,R103,R104,R105,R108,R111,R112,R113,R114,R115,R118,R121,R122,R131 | 74 | TT Electronics | ASC0402-2K2FT10 | RES 2.2k OHM 1/16W 1% 0402 | modbatt footprints:R_0402_1005Metric_Pad0.72x0.64mm_HandSolder | 9042107
6 | R6,R16,R26,R36,R46,R56,R66,R76,R86,R96,R106,R116,R123 | 13 | YAGEO | RT0402BRD0790K9L | RES 90.9k OHM 1/16W 0.1% 0402 | modbatt footprints:R_0402_1005Metric_Pad0.72x0.64mm_HandSolder | 9042165
7 | R7,R17,R27,R37,R47,R57,R67,R77,R87,R97,R107,R117,R124 | 13 | YAGEO | RT0402BRE0730K1L | RES 30.1k OHM 1/16W 0.1% 0402 | modbatt footprints:R_0402_1005Metric_Pad0.72x0.64mm_HandSolder | 9042163
8 | R9,R19,R28,R29,R39,R49,R59,R69,R79,R89,R99,R109,R119,R125,R126 | 15 | YAGEO | AC0402FR-134K7L | RES 4.7k OHM 1/16W 1% 0402 | modbatt footprints:R_0402_1005Metric_Pad0.72x0.64mm_HandSolder | 9042110
9 | R10,R20,R30,R40,R50,R60,R70,R80,R90,R100,R110,R120,R127 | 13 | YAGEO | RC1206JR-07100RL | RES 100 OHM 1/4W 5% 1206 | modbatt footprints:R_1206_3216Metric_Pad1.30x1.75mm_HandSolder | 9042026
10 | U1,U3,U5,U7,U9,U11,U13,U15,U17,U19,U21,U23,U25 | 13 | Microchip Technology | ATTINY45V-10SU | 8-bit Microcontrollers - MCU 4kB Flash 0.256kB EEPROM 6 I/O Pins | modbatt footprints:SOIC-8W_5.3x5.3mm_P1.27mm | 9042058
11 | U2,U4,U6,U8,U10,U12,U14,U16,U18,U20,U22,U24,U26 | 13 | Microchip Technology | MCP9843T-BE/ST | Board Mount Temperature Sensors JEDEC Serial output temp sensor, +/-1 deg C max accy | modbatt footprints:DFN-8-1EP_3x2mm_P0.5mm_EP1.36x1.46mm | 9042024

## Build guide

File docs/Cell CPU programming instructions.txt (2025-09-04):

***UPDATED 8/30/24!!***

* Programming is done via the Microchip Studio application, which can be found
here:

https://www.microchip.com/en-us/tools-resources/develop/microchip-studio

* Download a dummy Microchip Studio application for the Tiny45 - this is just
so all the settings are set up properly. Unzip somewhere. Only needs
to be done once:

http://www.synthcom.com/~nb/modbatt-CellCPU.zip

* Bring up Microchip Studio. Look for a file called XC8Application1.atsln.
Click "File" then "Open Project/Solution". If this was already done once,
it can be skipped over.

* Click on "Tool", and select the Atmel-ICE (plus a serial #), and interface
change to "ISP". Ensure DebugWire is not enabled!

---------

To program an image:

* Bring up Microchip Studio, and load the XC8Application1.atsln app. 

* Click "Tools", then "Device Programming"

* Connect the Atmel ICE to the target Attiny45.

* Ensure the tool is set to "Atmel-ICE"

* Ensure the Device is set to Attiny45

* Ensure the interface is ISP

* Click "Apply" next to "ISP"

* Turn on the target. There should be one red and one green LED on the
AVR ICE with one shut off.

* Click "Read" under "Device signature". It should return 0x1E9206.  Check Target Voltage. You should see the voltage provided
to the target, like 3.3V. If it reads low, it's possible the 6 pin
connector is on backwards.

* Click "Production File", navigate to the file CellCPU.elf, ensuring it is the latest version (8/30/24 or later!)

* Check the "Flash" and "Fuses" checkboxes.  "Erase memory before programming" and "Verify programmed content" should also be checked.

* Click "Program".  It should successfully verify flash but will FAIL to verify fuses, this is normal.

FUSES BELOW ARE FOR REFERENCE ONLY, DO NOT USE!
----------------------------------------------------------------------

EXTENDED.SELFPRGEN				Unchecked
HIGH.RSTDSBL					Checked
HIGH.DWEN						Unchecked
HIGH.SPEN						Unchecked
HIGH.WDTON						Unchecked
HIGH.EESAVE						Checked 
HIGH.BODLEVEL					Brown-out decetion at VCC=1.8V
LOW.CKDIV8						Checked
LOW.CKOUT						Unchecked
LOW SUT_CKSEL					Int. RC Osc. 8 Mhz Start-up time PWRDWN/RESET:6 CK/14 CK + 0ms

If selected properly, the final fuse register should look like this:

EXTENDED						0xff
HIGH							0x76
LOW								0x42

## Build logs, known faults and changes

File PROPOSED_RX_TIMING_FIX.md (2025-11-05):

# VUART RX Timing Fix for CPU #5 Corruption

## Corrected Problem Analysis

**Key Insight**: Each CPU retransmits at its own clock rate - drift does NOT accumulate through the chain!

**Actual Problem**: CPU #5's slow oscillator (-8% at 20°C) causes RX sampling drift over 10 bits:

```
CPU #5 running at 7.36MHz (-8%), timer tick = 1.087μs
Upstream transmitting at nominal 8MHz, bit time = 50.00μs

Bit 0: Sample at  27.2μs (should be 25.0μs) →  2.2μs late
Bit 1: Sample at  54.3μs (should be 50.0μs) →  4.3μs late
Bit 2: Sample at  81.5μs (should be 75.0μs) →  6.5μs late
Bit 8: Sample at 217.4μs (should be 200μs) → 17.4μs late (35% into bit!)
```

**Plus ISR overhead**: Each timer reschedule (line 135) takes 4-5 cycles before the actual `TIMER_CHA_INT()` macro executes. This adds ~5μs per bit.

**Combined effect**: By bit 8, CPU #5 is sampling 22μs late = 44% into the bit window → corrupted data!

## Current Code Issue

**vUART.c line 135** - Used by BOTH RX and TX states:
```c
TIMER_CHA_INT(VUART_BIT_TICKS-VUART_ISR_OVERHEAD);  // VUART_ISR_OVERHEAD = 0
```

**Problem**:
- During **RX** (relaying): Need to compensate for ISR overhead to maintain sampling accuracy
- During **TX** (originating): Want EXACT bit timing at processor's own clock rate

Currently `VUART_ISR_OVERHEAD = 0`, so NO compensation on RX!

## Proposed Solution

### Option 1: Separate RX and TX Overhead Constants (RECOMMENDED)

Add separate constants for RX vs TX timing compensation:

**Shared.h changes**:
```c
// Virtual UART timing - How many timer ticks is a single data/start/stop bit?
#define VUART_BIT_TICKS         50

// ISR overhead compensation for RECEIVE operations (empirical tuning)
// Compensates for code execution time before timer reschedule during RX
#define VUART_RX_ISR_OVERHEAD   5  // 5μs compensation for RX path

// ISR overhead compensation for TRANSMIT operations
// Set to 0 to maintain exact bit timing at processor's own clock rate
#define VUART_TX_ISR_OVERHEAD   0  // No compensation for TX - use native timing

// How far into the first data bit to sample after start bit detection
#define VUART_SAMPLE_OFFSET     ((VUART_BIT_TICKS / 2) - VUART_RX_ISR_OVERHEAD)
```

**vUART.c changes** (line 135):
```c
ISR(TIMER_COMPA_VECTOR, ISR_BLOCK)
{
    if (ESTATE_RX_DATA == sg_ecell_up_rxState)
    {
        // RX path - compensate for ISR overhead to maintain sampling accuracy
        TIMER_CHA_INT(VUART_BIT_TICKS - VUART_RX_ISR_OVERHEAD);

        // [rest of RX code]
    }
    else if (ESTATE_TX_DATA == sg_ecell_up_rxState)
    {
        // TX path - no compensation, use exact bit timing at CPU's clock rate
        TIMER_CHA_INT(VUART_BIT_TICKS - VUART_TX_ISR_OVERHEAD);

        // [rest of TX code]
    }
}
```

**Similarly for Channel B (line 170)**:
```c
ISR(TIMER_COMPB_VECTOR, ISR_BLOCK)
{
    // This is always RX path (cell_dn_rx -> cell_up_tx relay)
    TIMER_CHB_INT(VUART_BIT_TICKS - VUART_RX_ISR_OVERHEAD);

    // [rest of code]
}
```

### Option 2: State-Based Overhead (Alternative)

Keep single constant but apply it conditionally:

**Shared.h**:
```c
#define VUART_ISR_OVERHEAD   5  // Only used for RX
```

**vUART.c line 135**:
```c
ISR(TIMER_COMPA_VECTOR, ISR_BLOCK)
{
    if (ESTATE_RX_DATA == sg_ecell_up_rxState)
    {
        TIMER_CHA_INT(VUART_BIT_TICKS - VUART_ISR_OVERHEAD);  // RX: compensate
    }
    else if (ESTATE_TX_DATA == sg_ecell_up_rxState)
    {
        TIMER_CHA_INT(VUART_BIT_TICKS);  // TX: no compensation
    }
}
```

## Why This Fixes The Problem

**Current timing (broken)**:
```
RX: Schedule next sample at TCNT0 + 50 ticks
Actual interval: ISR overhead (~5μs) + 50 ticks = 55μs
With -8% oscillator: 55 × 1.087 = 59.8μs between samples!
After 8 bits: 59.8 - 50 = 9.8μs drift per bit × 8 = 78μs total drift
```

**With fix (VUART_RX_ISR_OVERHEAD = 5)**:
```
RX: Schedule next sample at TCNT0 + 45 ticks
Actual interval: ISR overhead (~5μs) + 45 ticks = 50μs target
With -8% oscillator: 50 × 1.087 = 54.35μs between samples
After 8 bits: 54.35 - 50 = 4.35μs drift per bit × 8 = 34.8μs total drift
Still within bit window! (50μs bit ± 25μs margin)
```

**TX remains unaffected**:
```
TX: Schedule next bit at TCNT0 + 50 ticks
Transmits at CPU's own clock rate (whatever that is)
Downstream receiver syncs on each start bit, so oscillator variance doesn't matter
```

## Testing Plan

1. **Measure actual ISR overhead**:
   - Use oscilloscope on profiler pins (if available on ATtiny261A)
   - Or estimate: Line 135 to line 148 ≈ 40-50 cycles @ 8MHz = 5-6μs

2. **Start with VUART_RX_ISR_OVERHEAD = 5**:
   - Rebuild CellCPU and ModuleCPU
   - Test CPU #5 at 20°C
   - Should see immediate improvement

3. **Fine-tune if needed**:
   - If still unreliable: increase to 6-7
   - If TOO aggressive (missing start of bits): decrease to 3-4

4. **Verify TX not affected**:
   - Confirm ModuleCPU still receives clean data
   - Check that inter-byte timing is consistent

## Implementation Recommendation

**Use Option 1** (separate constants) because:
1. Makes intent crystal clear (RX needs compensation, TX doesn't)
2. Easier to tune independently
3. Self-documenting code
4. Follows embedded best practice of explicit timing requirements

## Expected Result

CPU #5 (and any other marginal oscillators) will:
- Sample RX bits earlier in the window
- Compensate for ISR execution overhead
- Maintain sampling accuracy despite slow oscillator
- Still transmit at its own clock rate (which is fine - each start bit resyncs)

This should fix the corruption at 20°C without affecting any working CPUs.

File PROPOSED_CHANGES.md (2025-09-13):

# Proposed Edge Correction for CellCPU VUART Reception

## Problem
Temperature data showing -55.35°C (0x0000) indicates corrupted data during VUART reception. Without edge correction, timing drift during byte reception causes bit sampling errors.

## Solution
Implement edge-triggered timing correction similar to ModuleCPU's approach.

## Implementation Details

### 1. Add Edge Correction Variables
```c
// Edge correction tracking variables
static volatile int8_t sg_minTimingError_up;      // Min timing error on upstream
static volatile int8_t sg_maxTimingError_up;      // Max timing error on upstream  
static volatile uint16_t sg_edgeCorrections_up;   // Count of corrections on upstream
static volatile uint8_t sg_lastEdgeTimer_up;      // Timer value at last upstream edge

static volatile int8_t sg_minTimingError_dn;      // Min timing error on downstream
static volatile int8_t sg_maxTimingError_dn;      // Max timing error on downstream
static volatile uint16_t sg_edgeCorrections_dn;   // Count of corrections on downstream
static volatile uint8_t sg_lastEdgeTimer_dn;      // Timer value at last downstream edge

// Configuration
#define TIMING_TOLERANCE 3      // Only correct if error > 3 timer ticks
#define MAX_CORRECTION 5        // Maximum correction per edge
```

### 2. Modify PCINT ISR for Edge Detection Control
- After start bit detection, keep PCINT enabled for edge detection during byte
- Switch between monitoring specific pin vs any edge

### 3. Add Edge Correction Logic in PCINT ISR
During byte reception (ESTATE_RX_DATA state):
- Calculate timing error from expected mid-bit position
- If error > TIMING_TOLERANCE, resync timer to mid-bit
- Track min/max errors for diagnostics

### 4. Timer Tick Offset
- Define VUART_BIT_TICK_OFFSET (likely 6, same as current)
- Use for both initial sync and edge corrections

## Key Differences from ModuleCPU
- CellCPU uses PCINT for both pins (not INT1 like ModuleCPU)
- Must handle two independent receive channels (upstream and downstream)
- ATtiny45 has fewer resources - keep overhead minimal

## Testing Plan
1. Verify edge correction doesn't break basic VUART function
2. Check temperature data validity improves
3. Monitor correction statistics to verify it's working

## Risk Assessment
- **Low Risk**: Similar approach proven in ModuleCPU
- **Mitigation**: Can disable with #define if issues arise

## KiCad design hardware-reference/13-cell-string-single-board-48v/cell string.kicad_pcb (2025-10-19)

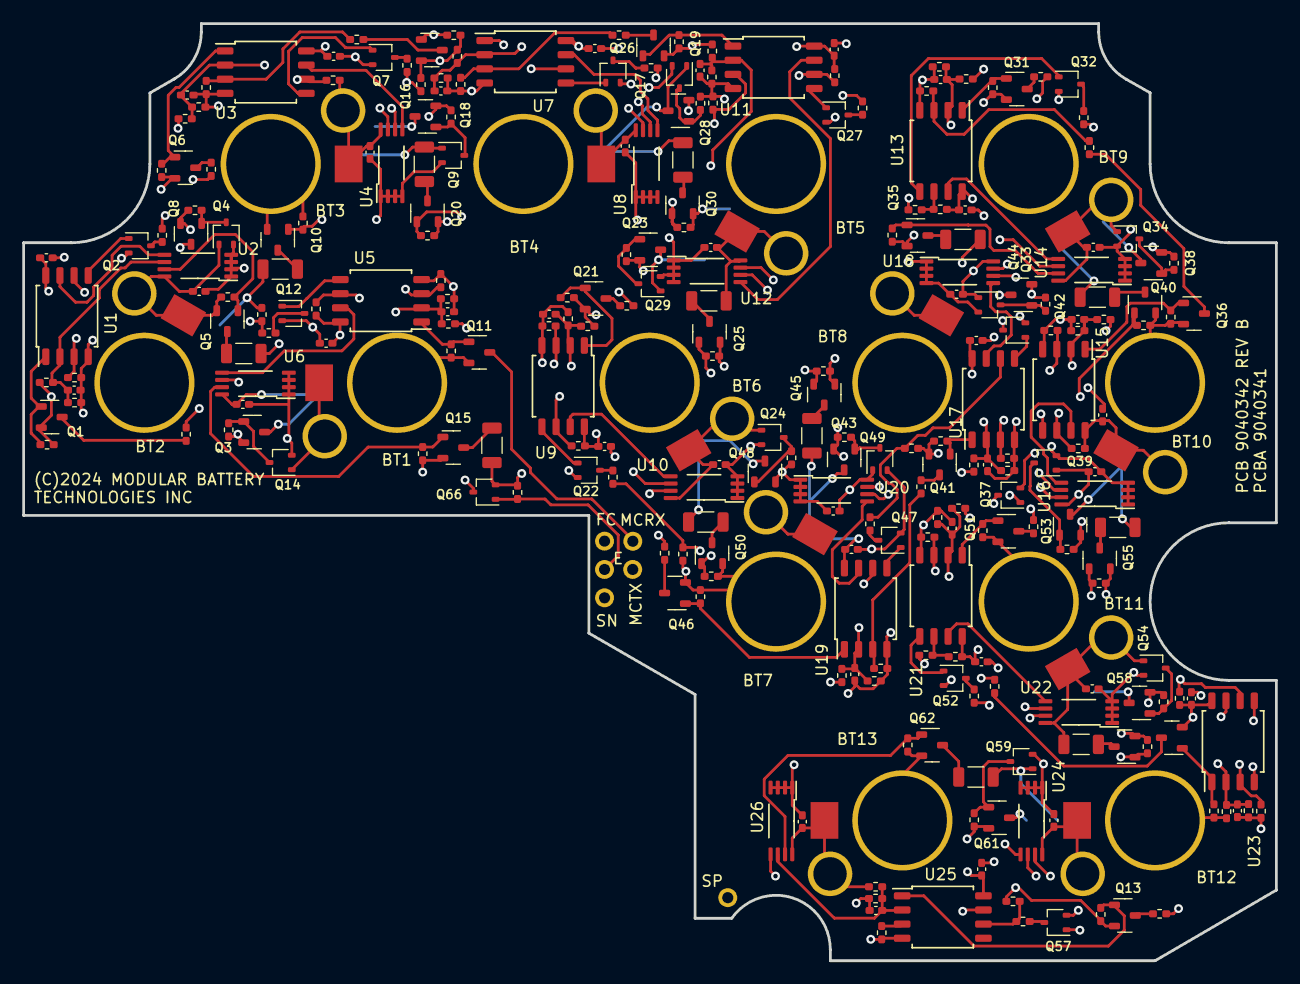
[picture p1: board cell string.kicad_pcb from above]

Board: 4 copper layers, 112.5 x 84.2 mm, 275 parts (0 on the bottom side), 168 nets.

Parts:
BT1, BT2, BT3, BT4, BT5, BT6, BT7, BT8, BT9, BT10, BT11, BT12, BT13: Battery_Cell; modbatt cell new
C1, C3, C4, C6, C7, C9, C10, C12, C13, C15, C16, C18, C19, C21, C22, C24, C25, C27, C28, C30, C31, C33, C34, C36, C37, C39: .1uF; C_0402_1005Metric_Pad0.74x0.62mm_HandSolder
C2, C5, C8, C11, C14, C17, C20, C23, C26, C29, C32, C35, C38: 10pF; C_0402_1005Metric_Pad0.74x0.62mm_HandSolder
J1, J2, J3, J4, J5, J6: Conn_01x01_Pin; PinHeader_1x01_P1.00mm_Horizontal
Q1, Q3, Q5, Q6, Q8, Q10, Q11, Q13, Q15, Q16, Q18, Q20, Q21, Q23, Q25, Q26, Q28, Q30, Q31, Q33, Q35, Q36, Q38, Q40, Q41, Q43, Q45, Q46, Q48, Q50, Q51, Q53, Q55, Q56, Q58, Q60, Q61, Q62: DMP3099L-7-HXY; SOT-23
Q2, Q4, Q7, Q9, Q12, Q14, Q17, Q19, Q22, Q24, Q27, Q29, Q32, Q34, Q37, Q39, Q42, Q44, Q47, Q49, Q52, Q54, Q57, Q59, Q66: 2N7002; SOT-323_SC-70
R1, R2, R3, R4, R5, R8, R11, R12, R13, R14, R15, R18, R21, R22, R23, R24, R25, R31, R32, R33, R34, R35, R38, R41, R42, R43, R44, R45, R48, R51, R52, R53, R54, R55, R58, R61, R62, R63, R64, R65, R68, R71, R72, R73, R74, R75, R78, R81, R82, R83, R84, R85, R88, R91, R92, R93, R94, R95, R98, R101, R102, R103, R104, R105, R108, R111, R112, R113, R114, R115, R118, R121, R122, R131: 2.2K; R_0402_1005Metric_Pad0.72x0.64mm_HandSolder
R6, R16, R26, R36, R46, R56, R66, R76, R86, R96, R106, R116, R123: 90.9k 0.1%; R_0402_1005Metric_Pad0.72x0.64mm_HandSolder
R7, R17, R27, R37, R47, R57, R67, R77, R87, R97, R107, R117, R124: 30.1k 0.1%; R_0402_1005Metric_Pad0.72x0.64mm_HandSolder
R9, R19, R28, R29, R39, R49, R59, R69, R79, R89, R99, R109, R119, R125, R126: 4.7K; R_0402_1005Metric_Pad0.72x0.64mm_HandSolder
R10, R20, R30, R40, R50, R60, R70, R80, R90, R100, R110, R120, R127: 100; R_1206_3216Metric_Pad1.30x1.75mm_HandSolder
U1, U3, U5, U7, U9, U11, U13, U15, U17, U19, U21, U23, U25: ATtiny45V-10SU; SOIC-8W_5.3x5.3mm_P1.27mm
U2, U4, U6, U8, U10, U12, U14, U16, U18, U20, U22, U24, U26: MCP9843T-BE/ST; DFN-8-1EP_3x2mm_P0.5mm_EP1.36x1.46mm

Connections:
/CELL EN: J6.1, Q66.1 (G), R131.1
/FIRST CELL: BT1.1 (+), C7.1, C9.1, J5.1, Q3.3, Q11.2, Q14.1 (G), Q15.2, R10.2, R22.1, R25.1, R26.1, R29.1, U5.8 (VCC), U6.8 (V_{DD})
/MC RX: J4.1, Q11.3
/MC TX: J3.1, R25.2, U5.6 (PB1)
/STRING NEG: J2.1, Q66.2 (S), R30.2, R131.2
/STRING POS: BT13.1 (+), C37.1, C39.1, J1.1, Q13.2, Q62.2, R28.1, R122.1, R123.1, R126.1, U25.8 (VCC), U26.8 (V_{DD})
/cell circuit1/CMGND: C7.2, C8.2, C9.2, Q12.2 (S), Q14.2 (S), Q66.3 (D), R21.2, R27.2, U5.4 (GND), U6.1 (A0), U6.2 (A1), U6.3 (A2), U6.4 (GND)
/cell circuit1/DN TX/RST: Q11.1, R22.2, U5.1 (~RESET/PB5)
/cell circuit1/SCL/VCELL: C8.1, R26.2, R27.1, U5.2 (XTAL1/PB3), U6.6 (SCL)
/cell circuit1/SDA: U5.7 (PB2), U6.5 (SDA)
/cell circuit1/UP TX: Q12.1 (G), U5.5 (AREF/PB0)
/cell circuit1/cell up rx: R3.2, R21.1, U5.3 (XTAL2/PB4)
/cell circuit1/cell up tx: R5.2, R24.1, U1.6 (PB1)
/cell circuit1/cell_en out: Q3.1, Q14.3 (D), R8.2
/cell circuit2/CMGND: C1.2, C2.2, C3.2, Q2.2 (S), Q3.2, Q4.2 (S), R1.2, R7.2, R8.1, U1.4 (GND), U2.1 (A0), U2.2 (A1), U2.3 (A2), U2.4 (GND)
/cell circuit2/DN TX/RST: Q1.1, R2.2, U1.1 (~RESET/PB5)
/cell circuit2/SCL/VCELL: C2.1, R6.2, R7.1, U1.2 (XTAL1/PB3), U2.6 (SCL)
/cell circuit2/SDA: U1.7 (PB2), U2.5 (SDA)
/cell circuit2/UP TX: Q2.1 (G), U1.5 (AREF/PB0)
/cell circuit2/cell plus: BT2.1 (+), C1.1, C3.1, Q1.2, Q4.1 (G), Q5.2, Q8.3, R2.1, R5.1, R6.1, R9.1, R20.2, U1.8 (VCC), U2.8 (V_{DD})
/cell circuit2/cell up rx: R1.1, R13.2, U1.3 (XTAL2/PB4)
/cell circuit2/cell up tx: R4.1, R15.2, U3.6 (PB1)
/cell circuit2/cell_en out: Q4.3 (D), Q8.1, R18.2
/cell circuit3/CMGND: C4.2, C5.2, C6.2, Q7.2 (S), Q8.2, Q9.2 (S), R11.2, R17.2, R18.1, U3.4 (GND), U4.1 (A0), U4.2 (A1), U4.3 (A2), U4.4 (GND)
/cell circuit3/DN TX/RST: Q6.1, R12.2, U3.1 (~RESET/PB5)
/cell circuit3/SCL/VCELL: C5.1, R16.2, R17.1, U3.2 (XTAL1/PB3), U4.6 (SCL)
/cell circuit3/SDA: U3.7 (PB2), U4.5 (SDA)
/cell circuit3/UP TX: Q7.1 (G), U3.5 (AREF/PB0)
/cell circuit3/cell plus: BT3.1 (+), C4.1, C6.1, Q6.2, Q9.1 (G), Q10.2, Q18.3, R12.1, R15.1, R16.1, R19.1, R40.2, U3.8 (VCC), U4.8 (V_{DD})
/cell circuit3/cell up rx: R11.1, R33.2, U3.3 (XTAL2/PB4)
/cell circuit3/cell up tx: R14.1, R35.2, U7.6 (PB1)
/cell circuit3/cell_en out: Q9.3 (D), Q18.1, R38.2
/cell circuit4/CMGND: C10.2, C11.2, C12.2, Q17.2 (S), Q18.2, Q19.2 (S), R31.2, R37.2, R38.1, U7.4 (GND), U8.1 (A0), U8.2 (A1), U8.3 (A2), U8.4 (GND)
/cell circuit4/DN TX/RST: Q16.1, R32.2, U7.1 (~RESET/PB5)
/cell circuit4/SCL/VCELL: C11.1, R36.2, R37.1, U7.2 (XTAL1/PB3), U8.6 (SCL)
/cell circuit4/SDA: U7.7 (PB2), U8.5 (SDA)
/cell circuit4/UP TX: Q17.1 (G), U7.5 (AREF/PB0)
/cell circuit4/cell plus: BT4.1 (+), C10.1, C12.1, Q16.2, Q19.1 (G), Q20.2, Q28.3, R32.1, R35.1, R36.1, R39.1, R60.2, U7.8 (VCC), U8.8 (V_{DD})
/cell circuit4/cell up rx: R31.1, R53.2, U7.3 (XTAL2/PB4)
/cell circuit4/cell up tx: R34.1, R55.2, U11.6 (PB1)
/cell circuit4/cell_en out: Q19.3 (D), Q28.1, R58.2
/cell circuit5/CMGND: C16.2, C17.2, C18.2, Q27.2 (S), Q28.2, Q29.2 (S), R51.2, R57.2, R58.1, U11.4 (GND), U12.1 (A0), U12.2 (A1), U12.3 (A2), U12.4 (GND)
/cell circuit5/DN TX/RST: Q26.1, R52.2, U11.1 (~RESET/PB5)
/cell circuit5/SCL/VCELL: C17.1, R56.2, R57.1, U11.2 (XTAL1/PB3), U12.6 (SCL)
/cell circuit5/SDA: U11.7 (PB2), U12.5 (SDA)
/cell circuit5/UP TX: Q27.1 (G), U11.5 (AREF/PB0)
/cell circuit5/cell plus: BT5.1 (+), C16.1, C18.1, Q23.3, Q26.2, Q29.1 (G), Q30.2, R50.2, R52.1, R55.1, R56.1, R59.1, U11.8 (VCC), U12.8 (V_{DD})
/cell circuit5/cell up rx: R43.2, R51.1, U11.3 (XTAL2/PB4)
/cell circuit5/cell up tx: R45.2, R54.1, U9.6 (PB1)
/cell circuit5/cell_en out: Q23.1, Q29.3 (D), R48.2
/cell circuit6/CMGND: C13.2, C14.2, C15.2, Q22.2 (S), Q23.2, Q24.2 (S), R41.2, R47.2, R48.1, U9.4 (GND), U10.1 (A0), U10.2 (A1), U10.3 (A2), U10.4 (GND)
/cell circuit6/DN TX/RST: Q21.1, R42.2, U9.1 (~RESET/PB5)
/cell circuit6/SCL/VCELL: C14.1, R46.2, R47.1, U9.2 (XTAL1/PB3), U10.6 (SCL)
/cell circuit6/SDA: U9.7 (PB2), U10.5 (SDA)
/cell circuit6/UP TX: Q22.1 (G), U9.5 (AREF/PB0)
/cell circuit6/cell plus: BT6.1 (+), C13.1, C15.1, Q21.2, Q24.1 (G), Q25.2, Q48.3, R42.1, R45.1, R46.1, R49.1, R100.2, U9.8 (VCC), U10.8 (V_{DD})
/cell circuit6/cell up rx: R41.1, R93.2, U9.3 (XTAL2/PB4)
/cell circuit6/cell up tx: R44.1, R95.2, U19.6 (PB1)
/cell circuit6/cell_en out: Q24.3 (D), Q48.1, R98.2
/cell circuit7/CMGND: C28.2, C29.2, C30.2, Q47.2 (S), Q48.2, Q49.2 (S), R91.2, R97.2, R98.1, U19.4 (GND), U20.1 (A0), U20.2 (A1), U20.3 (A2), U20.4 (GND)
/cell circuit7/DN TX/RST: Q46.1, R92.2, U19.1 (~RESET/PB5)
/cell circuit7/SCL/VCELL: C29.1, R96.2, R97.1, U19.2 (XTAL1/PB3), U20.6 (SCL)
/cell circuit7/SDA: U19.7 (PB2), U20.5 (SDA)
/cell circuit7/UP TX: Q47.1 (G), U19.5 (AREF/PB0)
/cell circuit7/cell plus: BT7.1 (+), C28.1, C30.1, Q43.3, Q46.2, Q49.1 (G), Q50.2, R90.2, R92.1, R95.1, R96.1, R99.1, U19.8 (VCC), U20.8 (V_{DD})
/cell circuit7/cell up rx: R83.2, R91.1, U19.3 (XTAL2/PB4)
/cell circuit7/cell up tx: R85.2, R94.1, U17.6 (PB1)
/cell circuit7/cell_en out: Q43.1, Q49.3 (D), R88.2
/cell circuit8/CMGND: C25.2, C26.2, C27.2, Q42.2 (S), Q43.2, Q44.2 (S), R81.2, R87.2, R88.1, U17.4 (GND), U18.1 (A0), U18.2 (A1), U18.3 (A2), U18.4 (GND)
/cell circuit8/DN TX/RST: Q41.1, R82.2, U17.1 (~RESET/PB5)
/cell circuit8/SCL/VCELL: C26.1, R86.2, R87.1, U17.2 (XTAL1/PB3), U18.6 (SCL)
/cell circuit8/SDA: U17.7 (PB2), U18.5 (SDA)
/cell circuit8/UP TX: Q42.1 (G), U17.5 (AREF/PB0)
/cell circuit8/cell plus: BT8.1 (+), C25.1, C27.1, Q33.3, Q41.2, Q44.1 (G), Q45.2, R70.2, R82.1, R85.1, R86.1, R89.1, U17.8 (VCC), U18.8 (V_{DD})
/cell circuit8/cell up rx: R63.2, R81.1, U17.3 (XTAL2/PB4)
/cell circuit8/cell up tx: R65.2, R84.1, U13.6 (PB1)
/cell circuit8/cell_en out: Q33.1, Q44.3 (D), R68.2
/cell circuit9/CMGND: C19.2, C20.2, C21.2, Q32.2 (S), Q33.2, Q34.2 (S), R61.2, R67.2, R68.1, U13.4 (GND), U14.1 (A0), U14.2 (A1), U14.3 (A2), U14.4 (GND)
/cell circuit9/DN TX/RST: Q31.1, R62.2, U13.1 (~RESET/PB5)
/cell circuit9/SCL/VCELL: C20.1, R66.2, R67.1, U13.2 (XTAL1/PB3), U14.6 (SCL)
/cell circuit9/SDA: U13.7 (PB2), U14.5 (SDA)
/cell circuit9/UP TX: Q32.1 (G), U13.5 (AREF/PB0)
/cell circuit10/CMGND: C22.2, C23.2, C24.2, Q37.2 (S), Q38.2, Q39.2 (S), R71.2, R77.2, R78.1, U15.4 (GND), U16.1 (A0), U16.2 (A1), U16.3 (A2), U16.4 (GND)
/cell circuit10/DN TX/RST: Q36.1, R72.2, U15.1 (~RESET/PB5)
/cell circuit10/SCL/VCELL: C23.1, R76.2, R77.1, U15.2 (XTAL1/PB3), U16.6 (SCL)
/cell circuit10/SDA: U15.7 (PB2), U16.5 (SDA)
/cell circuit10/UP TX: Q37.1 (G), U15.5 (AREF/PB0)
/cell circuit10/cell dn rx: R64.1, R75.2, U15.6 (PB1)
/cell circuit10/cell dn tx: R61.1, R73.2, U13.3 (XTAL2/PB4)
/cell circuit10/cell minus: BT9.1 (+), C19.1, C21.1, Q31.2, Q34.1 (G), Q35.2, Q38.3, R62.1, R65.1, R66.1, R69.1, R80.2, U13.8 (VCC), U14.8 (V_{DD})
/cell circuit10/cell plus: BT10.1 (+), C22.1, C24.1, Q36.2, Q39.1 (G), Q40.2, Q53.3, R72.1, R75.1, R76.1, R79.1, R110.2, U15.8 (VCC), U16.8 (V_{DD})
/cell circuit10/cell up rx: R71.1, R103.2, U15.3 (XTAL2/PB4)
/cell circuit10/cell up tx: R74.1, R105.2, U21.6 (PB1)
/cell circuit10/cell_en in: Q34.3 (D), Q38.1, R78.2
/cell circuit10/cell_en out: Q39.3 (D), Q53.1, R108.2
/cell circuit11/CMGND: C31.2, C32.2, C33.2, Q52.2 (S), Q53.2, Q54.2 (S), R101.2, R107.2, R108.1, U21.4 (GND), U22.1 (A0), U22.2 (A1), U22.3 (A2), U22.4 (GND)
/cell circuit11/DN TX/RST: Q51.1, R102.2, U21.1 (~RESET/PB5)
/cell circuit11/SCL/VCELL: C32.1, R106.2, R107.1, U21.2 (XTAL1/PB3), U22.6 (SCL)
/cell circuit11/SDA: U21.7 (PB2), U22.5 (SDA)
/cell circuit11/UP TX: Q52.1 (G), U21.5 (AREF/PB0)
/cell circuit11/cell plus: BT11.1 (+), C31.1, C33.1, Q51.2, Q54.1 (G), Q55.2, Q58.3, R102.1, R105.1, R106.1, R109.1, R120.2, U21.8 (VCC), U22.8 (V_{DD})
/cell circuit11/cell up rx: R101.1, R113.2, U21.3 (XTAL2/PB4)
/cell circuit11/cell up tx: R104.1, R115.2, U23.6 (PB1)
/cell circuit11/cell_en out: Q54.3 (D), Q58.1, R118.2
/cell circuit12/CMGND: C34.2, C35.2, C36.2, Q57.2 (S), Q58.2, Q59.2 (S), R111.2, R117.2, R118.1, U23.4 (GND), U24.1 (A0), U24.2 (A1), U24.3 (A2), U24.4 (GND)
/cell circuit12/DN TX/RST: Q56.1, R112.2, U23.1 (~RESET/PB5)
/cell circuit12/SCL/VCELL: C35.1, R116.2, R117.1, U23.2 (XTAL1/PB3), U24.6 (SCL)
/cell circuit12/SDA: U23.7 (PB2), U24.5 (SDA)
/cell circuit12/UP TX: Q57.1 (G), U23.5 (AREF/PB0)
/cell circuit12/cell plus: BT12.1 (+), C34.1, C36.1, Q56.2, Q59.1 (G), Q60.2, Q61.3, R112.1, R115.1, R116.1, R119.1, R127.2, U23.8 (VCC), U24.8 (V_{DD})
/cell circuit12/cell up rx: R111.1, R121.2, U23.3 (XTAL2/PB4)
/cell circuit12/cell up tx: R114.1, R122.2, U25.6 (PB1)
/cell circuit12/cell_en out: Q59.3 (D), Q61.1, R125.2
/cell circuit13/CMGND: C37.2, C38.2, C39.2, Q61.2, R23.2, R124.2, R125.1, U25.4 (GND), U26.1 (A0), U26.2 (A1), U26.3 (A2), U26.4 (GND)
/cell circuit13/DN TX/RST: Q13.1, R28.2, U25.1 (~RESET/PB5)
/cell circuit13/SCL/VCELL: C38.1, R123.2, R124.1, U25.2 (XTAL1/PB3), U26.6 (SCL)
/cell circuit13/SDA: U25.7 (PB2), U26.5 (SDA)
unnamed: Q1.3, R3.1
unnamed: Q2.3 (D), R4.2
unnamed: Q5.3, R10.1
unnamed: Q6.3, R13.1
unnamed: Q7.3 (D), R14.2
unnamed: Q10.3, R20.1
unnamed: Q12.3 (D), R24.2
unnamed: Q13.3, R121.1
unnamed: Q15.3, R30.1
unnamed: Q16.3, R33.1
unnamed: Q17.3 (D), R34.2
unnamed: Q20.3, R40.1
unnamed: Q21.3, R43.1
unnamed: Q22.3 (D), R44.2
unnamed: Q25.3, R50.1
unnamed: Q26.3, R53.1
unnamed: Q27.3 (D), R54.2
unnamed: Q30.3, R60.1
unnamed: Q31.3, R63.1
unnamed: Q32.3 (D), R64.2
unnamed: Q35.3, R70.1
unnamed: Q36.3, R73.1
unnamed: Q37.3 (D), R74.2
unnamed: Q40.3, R80.1
unnamed: Q41.3, R83.1
unnamed: Q42.3 (D), R84.2
unnamed: Q45.3, R90.1
unnamed: Q46.3, R93.1
unnamed: Q47.3 (D), R94.2
unnamed: Q50.3, R100.1
unnamed: Q51.3, R103.1
unnamed: Q52.3 (D), R104.2
unnamed: Q55.3, R110.1
unnamed: Q56.3, R113.1
unnamed: Q57.3 (D), R114.2
unnamed: Q60.3, R120.1
unnamed: Q62.3, R127.1
unnamed: Q5.1, R9.2, U2.7 (Event)
unnamed: Q10.1, R19.2, U4.7 (Event)
unnamed: Q15.1, R29.2, U6.7 (Event)
unnamed: Q20.1, R39.2, U8.7 (Event)
unnamed: Q25.1, R49.2, U10.7 (Event)
unnamed: Q30.1, R59.2, U12.7 (Event)
unnamed: Q35.1, R69.2, U14.7 (Event)
unnamed: Q40.1, R79.2, U16.7 (Event)
unnamed: Q45.1, R89.2, U18.7 (Event)
unnamed: Q50.1, R99.2, U20.7 (Event)
unnamed: Q55.1, R109.2, U22.7 (Event)
unnamed: Q60.1, R119.2, U24.7 (Event)
unnamed: R23.1, U25.3 (XTAL2/PB4)
unnamed: Q62.1, R126.2, U26.7 (Event)

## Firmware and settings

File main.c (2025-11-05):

/* CellCPU
 *
 * Cell controller firmware - main module
 *
 * (C) Copyright 2023-2024 Modular Battery Technologies, Inc.
 * US Patents 11,380,942; 11,469,470; 11,575,270; others. All
 * rights reserved
 */

// Uncomment to use fake cell data for testing
// #define FAKE_CELL_DATA

#include "Platform.h"
#include "I2c.h"
#include "mcp9843.h"
#include "adc.h"
#include "main.h"
#include "../ModuleCPU/Shared/Shared.h"
#include "vUART.h"
#include <avr/sleep.h>
#include <avr/wdt.h>

// Most recent ADC (battery voltage) reading
static uint16_t sg_u16BatteryVoltage;							// Latest battery voltage reading

// Most recent temperature reading
static volatile uint16_t sg_u16BatteryTemperature;				// Latest battery temperature reading

// Target voltage. If sg_u16BatteryVoltage is higher than sg_u16BatterVoltageTarget, 
// turn on the discharge resistor
static volatile uint16_t sg_u16BatteryVoltageTarget;			// Target battery voltage (most recently received)

// Set true if the battery is currently being discharged
static volatile bool sg_bDischargeActive;

// Set true if this is the last cell CPU in the chain. If set true,
// this cell CPU will initiate transmission.
static volatile bool sg_bCellCPULast;

// This is the 16 bit quantity we get from the module controller - raw
static uint16_t sg_u16BatteryVoltageMsg;


// What state are we in?
typedef enum
{
	EACTION_NONE,
	EACTION_SEND_SENSOR_READING,
	EACTION_SEND_PATTERN,
	EACTION_INIT,
	EACTION_INITIATE_TRANSMIT
} ECellAction;

// Cell action - used by ISR to signal foreground wakeup
static ECellAction sg_eCellAction;

// Delay for at least u16Ticks timer B overflow ticks. If u16Ticks is 0, it will quantize to the
// next timer tick change.
void Delay(uint16_t u16Ticks)
{
	uint8_t u8Sample;
	
	u16Ticks++;
	
	u8Sample = TIMER_COUNTER();
	while (u16Ticks)
	{
		// Wait until we quantize
		while (u8Sample == TIMER_COUNTER());
		
		u8Sample = TIMER_COUNTER();
		--u16Ticks;
	}
}

// *************************************************************************
// cell_up_rx->cell_dn_tx handlers. This is data received from upstream cell
// CPUs and is retransmitted to other cell CPUs or to a module controller.
// *************************************************************************

// For our existing message, we will transmit 4 bytes:
//
// 0 - LSB Voltage
// 1 - MSB Voltage	(bit 7: 1=Discharge active, 0=Discharge inactive)
// 2 - LSB Temperature
// 3 - MSB Temperature (bit 7: 1=Valid I2C reading, 0=I2C communication error)

static uint8_t sg_u8TransmitOffset;

// Returns true if cell data is available. See message above for the meaning of >=4
bool Celldn_txDataAvailable(void)
{
	// We signal no more data available at the 4th byte (offset 3)
	// but still need to transmit the final byte.
	if (sg_u8TransmitOffset >= 4)
	{
		return(false);
	}
	
	return(true);
}

// Returns the next byte of cell data we want to transmit to the next cell, etc... module controller
uint8_t Celldn_txDataGet(void)
{
	uint8_t u8Data = 0xff;
	
	if (0 == sg_u8TransmitOffset)
	{
		// 0 - LSB Voltage
		u8Data = (uint8_t) sg_u16BatteryVoltage;
	}
	else
	if (1 == sg_u8TransmitOffset)
	{
		// 1 - MSB Voltage
		u8Data = (uint8_t) (sg_u16BatteryVoltage >> 8);
	}
	else
	if (2 == sg_u8TransmitOffset)
	{
		// 2 - LSB Temperature
		u8Data = (uint8_t) sg_u16BatteryTemperature;
	}
	else
	if (3 == sg_u8TransmitOffset)
	{
		// 3 - MSB Temperature
		u8Data = (uint8_t) (sg_u16BatteryTemperature >> 8);
	}
	
	sg_u8TransmitOffset++;
	return(u8Data);
}

// Resets the cell data state machine if necessary. This is called upon the falling
// edge of the start of a receive stream.
void Celldn_txDataReset(void)
{
	// Offset back to 0
	sg_u8TransmitOffset = 0;
}

// Battery target receive globals
static uint8_t sg_u8dn_rxBitCount = 0;

// Called right before data is transmitted/appended
void Celldn_txTransmitStart(void)
{
	// Sending the 0th byte
	sg_u8TransmitOffset = 0;
}

// *************************************************************************
// cell_dn_rx->cell_up_tx handlers. Received from module controller or cell
// CPU and transmitted to other cells.
// *************************************************************************

// Incoming message from the module controller:
//
// 0 - MSB Of voltage target
// 1 - LSB Of voltage target
//
// The cell_dn_rx->cell_up_tx path must do MSB first because it relies on
// getting the top two bits of the 16 bit quantity to indicate the command
// type.

// Called when start of message from module controller or upstream is started
void Celldn_rxDataStart(void)
{
	sg_u8dn_rxBitCount = 0;
	sg_u16BatteryVoltageMsg = 0;
}

// All messages from the module controller are 16 bit message. The top bit
// indicates if it's a setting of a voltage target or if it's a reading
// request. Bit 14 indicates the type of reading. Look in main.h for
// MSG_CELL_SEND_REPORT, MSG_CELL_SEND_PATTERN, and MSG_CELL_SEND_SENSORS
// for further specific illustration.

// Called for each received bit from the dn_rx direction (from the module controller)
void Celldn_rxDataBit(uint8_t u8DataBit)
{
	sg_u16BatteryVoltageMsg <<= 1;
	sg_u16BatteryVoltageMsg |= u8DataBit;
	sg_u8dn_rxBitCount++;

	// Special case after reception of the second data bit - if this is
	// a request for a reading, then signal the foreground code to do
	// a sensor reading. This hastens the response time of the initial request.

	if (2 == sg_u8dn_rxBitCount)
	{
		// After the second bit, let's see if we send a report. If so, then flag it
		// and record the type. The shift is necessary because we haven't received all 
		// 16 bits yet - just look at the two that we've received.
		if (sg_u16BatteryVoltageMsg & (MSG_CELL_SEND_REPORT >> 14))
		{
			// Indicates we want the cell CPU to send a report. Figure out which type.
			if (sg_u16BatteryVoltageMsg & (MSG_CELL_SEND_PATTERN >> 14))
			{
				sg_eCellAction = EACTION_SEND_PATTERN;
			}
			else
			{
				// Send an actual sensor reading. On the CPU at the end of the
				// chain, this will cause a reading to occur, then it will
				// originate transmission up the chain by sending its reading
				// to the next neighboring CPU. If it's not the CPU on the end,
				// it will simply perform the reading and wait for the downstream
				// message to append itself to.
				sg_eCellAction = EACTION_SEND_SENSOR_READING;
			}
		}
		else
		{
			// This is a new discharge target - ignore it
		}
	}
	else
	if (16 == sg_u8dn_rxBitCount)
	{
		if (sg_u16BatteryVoltageMsg & MSG_CELL_SEND_REPORT)
		{
			// We don't do anything because it already happened at bit 2 above.
		}
		else
		{
			// New voltage target - no need to mask off the upper bits since they'll be 0 here
			sg_u16BatteryVoltageTarget = sg_u16BatteryVoltageMsg;
		}
		
		sg_u16BatteryVoltageMsg = 0;
	}
}

/*
static void PinSetup(void)
{
	cli();
	
	// Set up up_tx and dn_tx as outputs
	PIN_CELL_UP_TX_DDR |= (1 << PIN_CELL_UP_TX);
	PIN_CELL_DN_TX_DDR |= (1 << PIN_CELL_DN_TX);
	
	// And SCL/SDA
	I2C_PORT_DDR |= (1 << I2C_SDA_PIN) | (1 << I2C_SCL_PIN);
	// And pullups
	I2C_PORT |= (1 << I2C_SDA_PIN) | (1 << I2C_SCL_PIN);

	// Set up cell_dn_rx and cell_up_rx as inputs and turn on pullups
	PIN_CELL_DN_RX_DDR &= ~(1 << PIN_CELL_DN_RX);
	PIN_CELL_DN_RX_PORT |= (1 << PIN_CELL_DN_RX);
	
	PIN_CELL_UP_RX_DDR &= ~(1 << PIN_CELL_UP_RX);
	PIN_CELL_UP_RX_PORT |= (1 << PIN_CELL_UP_RX);
}

// Endlessly toggles all outputs
static void ToggleAllOutputs(void)
{
	PinSetup();
	
	while (1)
	{
		CELL_UP_TX_ASSERT();
		CELL_DN_TX_ASSERT();
		SCL_LOW();
		SDA_LOW();
		CELL_UP_TX_DEASSERT();
		CELL_DN_TX_DEASSERT();
		SCL_HIGH();
		SDA_HIGH();
	}
}

// Mirror cell_dn_rx->cell_up_tx and cell_up_rx->cell_dn_tx
static void InputMirror(void)
{
	PinSetup();
	
	while (1)
	{
		if (IS_PIN_CELL_DN_RX_ASSERTED())
		{
			CELL_UP_TX_ASSERT();
		}
		else
		{
			CELL_UP_TX_DEASSERT();
		}
		
		if (IS_PIN_CELL_UP_RX_ASSERTED())
		{
			CELL_DN_TX_ASSERT();
		}
		else
		{
			CELL_DN_TX_DEASSERT();
		}
	}
}
*/

int main(void)
{
	// Stop all interrupts
	cli();
	
	// Shut off the watchdog timer and reset reason
	MCUSR = 0;
	DISABLE_WDT();
	
	// Init CPU clock
	CPU_CLOCK_INIT();
	
	// Ensure pullups aren't globally disabled
	MCUCR &= (uint8_t) ~(1 << PUD);
	
	// Initialize virtual UART pins
	vUARTPinInit();
	
    // Set the ADC input to MUX_SELECT
    ADC_ADMUX_SET();
	
	// Drive cell_dn_tx low. This is required so we can detect if we're end-of-chain
	// or not.
	CELL_DN_TX_ASSERT();
	
	// Now init timer B
	TIMER_INIT();
	
	// Set battery target voltage so the event/discharge is forced off
	sg_u16BatteryVoltageTarget = 0xffff;
	
	// This will cause discharge to get shut off initially
	sg_bDischargeActive = true;

	// Turn on interrupt functionality but no specific interrupts
	INT_ENABLE();
	
	// First thing is an init/sensor read
	sg_eCellAction = EACTION_INIT;
	sg_bCellCPULast = true;  // assume we're last in the chain

	// Enable CPU interrupts
	sei();
	
	// Hang on forever!
	while (1)
	{
		uint16_t u16Voltage;
		uint16_t u16Temperature;

		if ((EACTION_SEND_SENSOR_READING == sg_eCellAction) ||
			(EACTION_SEND_PATTERN == sg_eCellAction) || 
			(EACTION_INIT == sg_eCellAction))
		{
			bool bDischargeActive = false;
			
			// Read the voltage first since the MUX is switched to the ADC
			// by default
			u16Voltage = ADCRead();
			sg_u16BatteryVoltage = u16Voltage;
			
			if (IS_PIN_CELL_UP_RX_ASSERTED())  // do a quick detect prior to sensor read, but check again after
			{
				// Pin is asserted, we're NOT the last CPU
				sg_bCellCPULast = false;
			}

			
			// Now temperature
			u16Temperature = MCP9843ReadTemperature();

			// Analog channel is now an input
			SCL_DISABLE();
			
			// Set SCL back to analog input
			ADC_ADMUX_SET();
			
			if (IS_PIN_CELL_UP_RX_ASSERTED())  // do a quick detect prior to possible event set, it may happen on some cells but not others
			{
				// Pin is asserted, we're NOT the last CPU
				sg_bCellCPULast = false;
			}
			
			
			// While we have I2C operational, let's evaluate the discharge
			// state and change it if it's updated
			if (u16Voltage > sg_u16BatteryVoltageTarget)
			{
				bDischargeActive = true;
			}
			
			// If the discharge state has changed, tell the MCP9843 about it
			if (bDischargeActive != sg_bDischargeActive)
			{
				sg_bDischargeActive = bDischargeActive;
				
				// Discharge is active LOW on the EVENT pin
				MCP9843SetEventPin(sg_bDischargeActive ? false : true);
				
				// Analog channel is now an input
				SCL_DISABLE();
			
				// Set SCL back to analog input
				ADC_ADMUX_SET();
			}
			
			// If we're discharging, update the battery voltage message
			if (sg_bDischargeActive)
			{
				// Set the upper bit to indicate we're actively discharging
				u16Voltage |= MSG_CELL_DISCHARGE_ACTIVE;
			}
			
			// If this is set, it will originate (or propagate) a pattern
			if (EACTION_SEND_PATTERN == sg_eCellAction)
			{
				sg_u16BatteryTemperature = PATTERN_TEMPERATURE;
				sg_u16BatteryVoltage = PATTERN_VOLTAGE;
			}
			else
			{
				// We're sending the actual reading
				sg_u16BatteryTemperature = u16Temperature;
				sg_u16BatteryVoltage = u16Voltage;
			}
		
			// If we're just initializing, go back to sleep. We only needed
			// the first pass to set the discharge/charge state
			// do a sample window for last cpu detection to account for any differences in arriving at this point between adjacent cpus due to I2C
			if (EACTION_INIT == sg_eCellAction)
			{
				uint8_t sample_count = 10;  //number of times to sample UP_RX for last cpu detection
				sg_eCellAction = EACTION_NONE;
				
				// sample every 1ms
				while (sample_count--)
				{
				// If at any point we see the pin asserted, we're NOT the last
					if (IS_PIN_CELL_UP_RX_ASSERTED())
					{
						// Pin is asserted, we're NOT the last CPU
						sg_bCellCPULast = false;
					}
					Delay(1000);  //this also gives the cell below more time to detect us
				}

				
				// If we're not the last cell CPU, turn on receive interrupts
				if (false == sg_bCellCPULast)
				{
					// Initialize the UART for receive operation (from cell CPUs to module CPUs)
					vUARTInitReceive();
				}
				else
				{
					// Last cell CPU in the chain - not needed and will just generated spurious
					// interrupts.
				}
		
				
				// Initialize transmit communication for module->cell->cell... communication
				CELL_DN_TX_DEASSERT();				// end of last detect sample window for cell below
				vUARTInitTransmit(); 
			}
			else
			{
				// We're doing a send of the data!
				sg_eCellAction = EACTION_INITIATE_TRANSMIT;
			}
		}
	
		if (EACTION_INITIATE_TRANSMIT == sg_eCellAction)
		{
			sg_eCellAction = EACTION_NONE;
			
			
			// If we're the last CPU, then we initiate transmit, otherwise we
			// don't do anything - we wait for the last CPU to start the message
			// transmission.
			if (true == sg_bCellCPULast)
			{
				// While we're receiving something, don't transmit anything. In practice, this
				// should never loop, but during development, it might.
				while (vUARTIscell_dn_rxActive());
				
				// Start transmission. Note this routine stops and starts interrupts, too.
				vUARTStartcell_dn_tx(VUART_BIT_TICKS/2);
			}
		}
		
		// SLEEP - The CPU will wake up on the next interrupt
//		set_sleep_mode(SLEEP_MODE_IDLE);
//		sleep_mode();
	}
}

// NOTE: If you're getting unexpected AVR resets, uncomment these unused handlers to see
// if another interrupt is being taken that doesn't have a handler. AVR Defaults to jumping
// to 0 when not vector is programmed.

ISR(INT0_vect, ISR_BLOCK)
{
	while (1);
}

ISR(TIMER1_OVF_vect, ISR_BLOCK)
{
	while (1);
}

ISR(TIMER0_OVF_vect, ISR_BLOCK)
{
	while (1);
}

ISR(USI_START_vect, ISR_BLOCK)
{
	while (1);
}

ISR(USI_OVF_vect, ISR_BLOCK)
{
	while (1);
}

ISR(EE_RDY_vect, ISR_BLOCK)
{
	while (1);
}

ISR(ANA_COMP_vect, ISR_BLOCK)
{
	while (1);
}

ISR(INT1_vect, ISR_BLOCK)
{
	while (1);
}

ISR(TIMER0_CAPT_vect, ISR_BLOCK)
{
	while (1);
}

ISR(TIMER1_COMPD_vect, ISR_BLOCK)
{
	while (1);
}

ISR(FAULT_PROTECTION_vect, ISR_BLOCK)
{
	while (1);
}

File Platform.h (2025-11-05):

/* CellCPU
 *
 * Cell controller firmware - Platform specific definitions (mini-HAL)
 *
 * (C) Copyright 2023-2024 Modular Battery Technologies, Inc.
 * US Patents 11,380,942; 11,469,470; 11,575,270; others. All
 * rights reserved
 */

#ifndef _PLATFORM_H_
#define _PLATFORM_H_

// Common to all processors
#include <stdint.h>
#include <xc.h>
#include <stdbool.h>
#include <avr/io.h>
#include <avr/interrupt.h>

/*
 * Cell CPU definitions:
 *
 * PB0 - cell up tx
 * PB1 - cell dn rx
 * PB2 - I2C SDA
 * PB3 - I2C SDL/ADC1 (sense cell plus voltage through resistor divider)
 * PB4 - cell up rx
 * PB5 - cell dn tx (note: This has the net effect of inverting the signal between CPUs)
 *
 * Discharge is on the MPC9843T on the "event" pin. MCP9843T is at I2C addresses (A0-A2 are low):
 *
 * Temperature sensor		- 0x30
 * EEPROM					- 0xa0
 * EEPROM Write protect	-	- 0x60
 */

// Specific CPU defines

#if defined(__AVR_ATtiny25__) || defined(__AVR_ATtiny45__)

// *************************************************************************************************
// ATTINY25/45 defines
// *************************************************************************************************

#define CPU_CLOCK_INIT()					CLKPR = (1 << CLKPCE); CLKPR = 0; PCMSK = 0; PRR = 0;
#define TIMER_INIT()						TCCR0A = 0; TCCR0B = (1 << CS01); TCNT0 = 0;	// /8 On main CPU
#define TIMER_COUNTER()						TCNT0
#define TIMER_OVF_VECTOR					TIM0_OVF_vect
#define PCINT_VECTOR						PCINT0_vect
#define TIMER_COMPA_VECTOR					TIM0_COMPA_vect
#define TIMER_COMPB_VECTOR					TIM0_COMPB_vect

// ADC Input related
#define ADC_ADMUX_SET()						ADMUX = (1 << MUX1) | (1 << MUX0) | (1 << REFS1)		// ADC3, internal 1.1V reference

#define	INT_ENABLE()						GIMSK = (1 << PCIE); MCUCR = (MCUCR & ~3) | (1 << ISC00);	// Set to logical pin change interrupt - ensure INT0 isn't active

#define PIN_CELL_DN_RX						PB1
#define PIN_CELL_DN_RX_PORT					PORTB
#define PIN_CELL_DN_RX_DDR					DDRB
#define PIN_CELL_DN_RX_PIN					PINB
#define PIN_CELL_DN_RX_INT					PCINT1

#define PIN_CELL_UP_TX						PB0
#define PIN_CELL_UP_TX_PORT					PORTB
#define	PIN_CELL_UP_TX_DDR					DDRB
#define	PIN_CELL_UP_TX_PIN					PINB

#define PIN_CELL_UP_RX						PB4
#define	PIN_CELL_UP_RX_PORT					PORTB
#define PIN_CELL_UP_RX_DDR					DDRB
#define PIN_CELL_UP_RX_PIN					PINB
#define PIN_CELL_UP_RX_INT					PCINT4

#define PIN_CELL_DN_TX						PB5
#define PIN_CELL_DN_TX_PORT					PORTB
#define PIN_CELL_DN_TX_DDR					DDRB
#define PIN_CELL_DN_TX_PIN					PINB

// CELL_UP_TX macros
#define CELL_UP_TX_ASSERT()					PIN_CELL_UP_TX_PORT |= ((uint8_t) (1 << PIN_CELL_UP_TX))
#define CELL_UP_TX_DEASSERT()				PIN_CELL_UP_TX_PORT &= ((uint8_t) ~(1 << PIN_CELL_UP_TX))

// CELL_DN_TX macros
#define CELL_DN_TX_ASSERT()					PIN_CELL_DN_TX_PORT &= ((uint8_t) ~(1 << PIN_CELL_DN_TX));
#define CELL_DN_TX_DEASSERT()				PIN_CELL_DN_TX_PORT |= ((uint8_t) (1 << PIN_CELL_DN_TX));

// Receive macros
#define	IS_PIN_CELL_DN_RX_ASSERTED()		(0 == IS_PIN_CELL_DN_RX_DEASSERTED())
#define IS_PIN_CELL_DN_RX_DEASSERTED()		((1 << PIN_CELL_DN_RX) & PIN_CELL_DN_RX_PIN)

#define IS_PIN_CELL_UP_RX_ASSERTED()		((1 << PIN_CELL_UP_RX) & PIN_CELL_UP_RX_PIN)
#define IS_PIN_CELL_UP_RX_DEASSERTED()		(0 == IS_PIN_CELL_UP_RX_ASSERTED())

// External interrupt enables
#define INT_CELL_DN_RX_ENABLE()				PCMSK |= (1 << PIN_CELL_DN_RX_INT)	// PCINT1
#define INT_CELL_DN_RX_DISABLE()			PCMSK &= (uint8_t) ~(1 << PIN_CELL_DN_RX_INT)

#define INT_CELL_UP_RX_ENABLE()				PCMSK |= (1 << PIN_CELL_UP_RX_INT)	// PCINT4
#define INT_CELL_UP_RX_DISABLE()			PCMSK &= (uint8_t) ~(1 << PIN_CELL_UP_RX_INT)

#define TIMER_CHA_INT(x)					OCR0A = (uint8_t) (TIMER_COUNTER() + (x)); TIMER_CHA_INT_CLEAR(); TIMSK |= (1 << OCIE0A)
#define TIMER_CHA_INT_CLEAR()				TIFR = (1 << OCF0A);
#define TIMER_CHB_INT(x)					OCR0B = (uint8_t) (TIMER_COUNTER() + (x)); TIMER_CHB_INT_CLEAR(); TIMSK |= (1 << OCIE0B)
#define TIMER_CHB_INT_CLEAR()				TIFR = (1 << OCF0B);
#define TIMER_CHA_INT_DISABLE()				TIMSK &= (uint8_t) ~(1 << OCIE0A)
#define TIMER_CHB_INT_DISABLE()				TIMSK &= (uint8_t) ~(1 << OCIE0B)

// Profiling bits
// Using PB2 (I2C SDA) for profiling during VUART RX operations
// Pin is automatically switched between profiler (OUTPUT) and I2C (INPUT) modes
// by PROFILER_ENABLE_OUTPUT() / PROFILER_RESTORE_I2C() in vUART.c
#define PROFILER_INIT()						// No-op, pin configured on-demand
#define PROFILER_ENABLE_OUTPUT()			DDRB |= (1 << PORTB2)				// Configure PB2 as OUTPUT for profiler
#define PROFILER_RESTORE_I2C()				DDRB &= (uint8_t) ~(1 << PORTB2); PORTB |= (1 << PORTB2)	// Return to I2C SDA (INPUT with pullup)
#define PROF_1_ASSERT()						PORTB |= (1 << PORTB2)
#define PROF_1_DEASSERT()					PORTB &= (uint8_t) ~(1 << PORTB2)
#define PROF_2_ASSERT()
#define PROF_2_DEASSERT()

// I2C Port
#define I2C_PORT							PORTB
#define I2C_PORT_READ						PINB
#define I2C_PORT_DDR						DDRB

// I2C Pins on that port
#define I2C_SDA_PIN							PORTB2
#define I2C_SCL_PIN							PORTB3

// WDT Defines (for 1hz periodic timer callback)
#define WDT_INIT							(1 << WDE) | (1 << WDCE) | (1 << WDIE) | WDT_TIMEOUT;
#define	DISABLE_WDT()						WDTCR |= (1 << WDCE) | (1 << WDE); WDTCR = 0;
#define ENABLE_1HZ_WDT()					WDTCR |= (1 << WDIE); WDTCR = WDT_INIT;

#elif defined(__AVR_ATtiny261A__)

// *************************************************************************************************
// ATTINY261A defines - Used on the Beavis board
// *************************************************************************************************

// Internal 8Mhz clock 
#define CPU_CLOCK_INIT()					CLKPR = (1 << CLKPCE); CLKPR = 0; PRR = 0; PCMSK0 = 0; PCMSK1 = 0;
#define TIMER_INIT()						TCCR0A = 0; TCCR0B = (1 << CS01); TCNT0L = 0; TCNT0H = 0;  
#define TIMER_COUNTER()						TCNT0L
#define TIMER_OVF_VECTOR					TIMER0_OVF_vect
#define PCINT_VECTOR						PCINT_vect
#define TIMER_COMPA_VECTOR					TIMER0_COMPA_vect
#define TIMER_COMPB_VECTOR					TIMER0_COMPB_vect

// ADC Input related
#define ADC_ADMUX_SET()						ADMUX = 0		// ADC0, VCC reference

// Initializes the interrupt subsystem to receive pin change interrupts
// but does not enable interrupts on any specific pin
#define	INT_ENABLE()						GIMSK |= (1 << PCIE0) | (1 << PCIE1); MCUCR = (MCUCR & ~3) | (1 << ISC00);

#define PIN_CELL_DN_RX						PORTA6		// PA6/PCINT6
#define PIN_CELL_DN_RX_PORT					PORTA
#define PIN_CELL_DN_RX_DDR					DDRA
#define PIN_CELL_DN_RX_PIN					PINA

#define PIN_CELL_UP_TX						PORTA7		// PA7/ADC6/AIN1
#define PIN_CELL_UP_TX_PORT					PORTA
#define	PIN_CELL_UP_TX_DDR					DDRA
#define	PIN_CELL_UP_TX_PIN					PINA

#define PIN_CELL_UP_RX						PORTB4		// XTAL2/CLKO/ADC2/OC1B/PCINT4
#define	PIN_CELL_UP_RX_PORT					PORTB
#define PIN_CELL_UP_RX_DDR					DDRB
#define PIN_CELL_UP_RX_PIN					PINB

#define PIN_CELL_DN_TX						PORTB5		// RESET/dW/ADC0/PCINT5
#define PIN_CELL_DN_TX_PORT					PORTB
#define PIN_CELL_DN_TX_DDR					DDRB
#define PIN_CELL_DN_TX_PIN					PINB
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

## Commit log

2025-09-13 feat(vuart): implement edge-triggered timing correction for VUART reception
    - Added edge correction for both upstream (cell_up_rx) and downstream (cell_dn_rx) reception
    - Tracks timing errors and applies corrections when drift exceeds tolerance
    - Keeps PCINT enabled during byte reception to detect bit edges
    - Uses same approach as proven in ModuleCPU
    - Should fix temperature data corruption (showing -55.35°C)
    The edge correction resynchronizes the sampling point to mid-bit position
    whenever a bit transition is detected, preventing timing drift from
    accumulating during byte reception.
    [vUART.c]
2025-09-13 refactor(vuart): simplify edge correction to always resync
    - Removed conditional correction logic (TIMING_TOLERANCE, MAX_CORRECTION)
    - Now always resyncs timer on every edge, same as ModuleCPU
    - Keeps diagnostic tracking but simplifies the correction logic
    - More aggressive correction should better handle timing drift
    [vUART.c]
2025-09-13 refactor(vuart): remove diagnostic tracking to save CPU cycles
    - Removed all timing error tracking variables and calculations
    - CellCPU has no debug capability due to restricted pin count
    - Keeps only the essential edge correction: resync timer on every edge
    - Saves CPU cycles and RAM on resource-constrained ATtiny45
    [vUART.c]
2025-09-14 Fix VUART reception start timing for both channels
    - Fixed cell_up_rx: Now uses VUART_BIT_TICKS + (VUART_BIT_TICKS/2) - VUART_BIT_TICK_OFFSET
    - Fixed cell_dn_rx: Now uses VUART_BIT_TICKS + (VUART_BIT_TICKS/2) - VUART_BIT_TICK_OFFSET
    - Both channels now properly sample at middle of first data bit
    - Accounts for ISR response overhead with VUART_BIT_TICK_OFFSET
    - Matches corrected formula from ModuleCPU implementation
    [vUART.c]
2025-09-19 Disable FAKE_CELL_DATA - use real sensor data
2025-09-22 revert: remove edge sync from VUART to fix relay timing corruption
    Edge sync was causing variable bit widths in the relayed signal because
    the same timer controls both input sampling and output generation.
    Adjusting the timer for better reception corrupted the downstream
    transmission timing.
    Reverted to original fixed-timing approach that maintains consistent
    relay timing at the cost of occasional bit errors from clock drift.
    Added EDGE_SYNC_ANALYSIS.md documenting the issue and potential future
    solutions that could decouple sampling from output timing.
    [vUART.c]
2025-09-22 fix: correct date in edge sync revert comments (09/2025 not 12/2024)
    [vUART.c]
2025-09-22 restore: vUART.c to original pre-edge-sync version
    Restoring to the initial known-good version from commit 7327a13.
    The edge sync experiments and revert remain in git history for reference.
    This gives us a clean baseline for any future improvements.
    [vUART.c]
2025-10-19 docs: Add hardware-reference README with complete patent list
    - Include all 14 ModBatt patents (13 issued, 1 pending)
    - Clarify non-commercial patent grant for educational/research use
    - Add comprehensive AS-IS warranty disclaimer
    - Detail battery safety warnings and liability limitations
    - Specify regulatory compliance responsibilities
    - Document commercial licensing requirements
2025-10-19 added hardware reference
    [CELL STRING.kicad_sch, cell circuit FIRST.kicad_sch, cell circuit LAST.kicad_sch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]
2025-10-19 docs: Update cell count from 94 to 128 cells
    - Change daisy-chain capacity from 94 to 128 cells
    - 94 was circumstantial, not a technical limitation
    - Update README and hardware-reference documentation
2025-11-05 Move Shared headers to ModuleCPU and add VUART RX timing fix
    Step 1: Relocate Shared files to ModuleCPU/Shared
    - Copied Shared.h and protocol docs to ModuleCPU/Shared/
    - Shared/ is now tracked in ModuleCPU git repo instead of standalone
    Step 2: Update CellCPU include paths
    - Changed ../Shared/Shared.h to ../ModuleCPU/Shared/Shared.h
    - Modified: main.c, mcp9843.c, vUART.c
    Step 3: Add VUART RX/TX timing separation
    - Shared.h: Added VUART_RX_ISR_OVERHEAD = 3, VUART_TX_ISR_OVERHEAD = 0
    - vUART.c: Separate timer compensation for RX (needs overhead comp) vs TX (exact timing)
    - Fixes CPU #5 corruption issue caused by slow oscillator + ISR overhead
    Analysis docs:
    - CELL5_CORRUPTION_ANALYSIS.md: D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
    [main.c, mcp9843.c, vUART.c]
2025-11-05 feat(profiler): add profiler support for RX timing analysis
    Added profiler output on PB2 (I2C SDA pin) to visualize VUART RX sampling timing:
    - Platform.h: Added PROF_1_ASSERT/DEASSERT macros using PB2
    - vUART.c: Added profiler pulses around RX bit sampling in TIMER_COMPA_VECTOR ISR
    The profiler shows when upstream data is being sampled, allowing oscilloscope
    verification of VUART_RX_ISR_OVERHEAD timing compensation.
    IMPORTANT: Profiler macros are disabled by default. Only enable when needed, as PB2
    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
2025-11-05 feat(profiler): enable profiler with automatic I2C pin management
    Modified profiler to automatically switch I2C SDA pin between profiler (OUTPUT)
    and I2C (INPUT) modes during VUART operations:
    Platform.h:
    - Added PROFILER_ENABLE_OUTPUT() to configure SDA pin as OUTPUT for profiler
    - Added PROFILER_RESTORE_I2C() to restore SDA pin as INPUT with pullup for I2C
    - Profiler macros now enabled by default (no manual commenting needed)
    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

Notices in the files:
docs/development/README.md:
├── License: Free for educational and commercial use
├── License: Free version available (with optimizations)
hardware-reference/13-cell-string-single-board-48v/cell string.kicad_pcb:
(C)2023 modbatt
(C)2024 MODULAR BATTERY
